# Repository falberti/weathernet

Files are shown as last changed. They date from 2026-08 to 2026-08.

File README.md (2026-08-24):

# WeatherNet

WeatherNet is a small telemetry platform for a network of DIY
environmental monitoring devices ("probes"). A probe reads sensor data
and device health metrics and reports them over mutual TLS to a server,
which validates the probe against a registry, stores the data in
TimescaleDB, and makes it visible in Grafana. Version 1 targets a
single Raspberry Pi probe and a single server, but the probe's sensor
framework and the server's registry are both built to add more probes
and hardware types later without a rewrite.

## Architecture

```
                          ┌──────────────────────────────────────────────────┐
                          │  Server VM (public IP, no DNS)                   │
                          │                                                  │
  ┌──────────┐  mTLS      │  ┌────────┐   verified    ┌────────┐             │
  │  Probe   │───────────▶│  │ nginx  │──cert CN hdr─▶│ django │             │
  │ (RPi,    │  HTTPS/443 │  │ (TLS + │               │        │──┐          │
  │ systemd, │            │  │ mTLS   │               └────────┘  │writes    │
  │ no       │            │  │ term.) │                           ▼          │
  │ Docker)  │            │  └────────┘               ┌────────────────────┐ │
  └──────────┘            │                           │ postgres +         │ │
                          │                           │ timescaledb ext.   │ │
                          │                           │ (registry tables + │ │
                          │                           │  sensor/health     │ │
                          │                           │  hypertables)      │ │
                          │                           └──────────┬─────────┘ │
                          │                                      │reads      │
                          │                                      ▼           │
                          │                                 ┌────────┐       │
                          │                                 │ grafana│       │
                          │                                 └────────┘       │
                          └──────────────────────────────────────────────────┘
```

Every telemetry payload goes `probe → nginx (mTLS termination) → Django
ingestion endpoint → TimescaleDB hypertables`. Probes never talk to
Postgres or Grafana directly, and Django cross-checks every probe's
identity (from its client certificate) against the registry before
writing anything -- deactivating a probe in Django Admin actually stops
its data, not just hides it. See [`PROJECT_SPEC.md`](PROJECT_SPEC.md)
for the full design rationale and [`docs/api-contract.md`](docs/api-contract.md)
for the exact ingestion payload schema.

Separately, each probe also maintains an outbound **WireGuard** tunnel
to the server, purely for operator troubleshooting (e.g. SSHing into a
probe sitting behind a home NAT). It's an independent channel from the
mTLS telemetry path above -- unrelated to probe authentication for
ingestion, and not gated by a probe's `is_active` flag. See
[Section 3](PROJECT_SPEC.md#3-architecture) and
[Section 5.8](PROJECT_SPEC.md#58-remote-access-via-wireguard-ongoing-operation)
of the spec.

A third path exists for exactly one moment per probe: **enrollment**. A
brand-new probe has no mTLS certificate yet, so it can't use mTLS to
bootstrap itself -- a single-use, short-lived token (generated in
Django Admin) stands in for that first credential exchange instead.
See [Section 5.7](PROJECT_SPEC.md#57-zero-touch-probe-enrollment) of
the spec for the full design.

## Prerequisites

**Server**: a VM with Docker and the Docker Compose plugin, a public
IP, and inbound access open on `443` (nginx/ingestion), Grafana's port
(`3000` by default), and the WireGuard UDP port (`51820` by default).

**Probe**: a Raspberry Pi (3 or newer) running a current Raspberry Pi
OS, Python 3, and network reachability to the server on `443`.

## Server setup

1. On the server, clone this repo and `cd server/`.
2. Generate the internal CA and server certificate (skip this if you'd
   rather let `scripts/setup.sh` do it for you -- it calls these
   automatically):
   ```bash
   ./pki/generate-ca.sh
   ./pki/generate-server-cert.sh <server-public-ip>
   ```
3. Run setup:
   ```bash
   ./scripts/setup.sh <server-public-ip>
   ```
   This generates `.env` (with a fresh `SECRET_KEY` and random
   passwords) if it doesn't already exist, builds and starts the Docker
   Compose stack, runs migrations (which also create the TimescaleDB
   hypertables and their compression/retention policies), prompts you
   to create a Django Admin superuser, and generates the server's
   WireGuard keypair and brings up its `wg0` interface.
4. When it finishes, the script prints the Grafana and Django Admin
   URLs and installs a systemd timer that keeps WireGuard peers in sync
   automatically -- no manual step needed there going forward.

## Probe setup

This is genuinely one command on the probe side -- zero-touch
enrollment (see above) means there's no manual certificate, UUID, or
WireGuard key exchange to do by hand.

1. In Django Admin, add an **Enrollment token**: fill in the probe's
   name and hardware type, save. The resulting page prints a one-time
   token and the *exact* command to run on the probe, including the
   server's IP and its certificate fingerprint (for TLS pinning) --
   nothing to copy from anywhere else.
2. On the probe device, clone this repo and `cd probe/`.
3. Run the command Django printed:
   ```bash
   ./scripts/setup.sh --server <server-public-ip> --token <token> --fingerprint <sha256-fingerprint>
   ```
   This creates a virtualenv, generates the probe's mTLS and WireGuard
   keypairs locally (private keys never leave the device), verifies the
   server's certificate against the given fingerprint before sending
   anything, exchanges the token for a signed certificate and an
   assigned WireGuard tunnel IP, writes `probe.yaml` and `wg0.conf`, and
   installs + starts both the `weathernet-probe` and `wg-quick@wg0`
   systemd services.
4. That's it. The probe should appear in Grafana within its report
   interval, and become SSH-reachable at its WireGuard tunnel IP from
   the server within about a minute (the timer installed during server
   setup picks it up automatically).

`--fingerprint` is optional but recommended -- without it, the probe
still enrolls, but has no way to confirm it's actually talking to your
server for that one bootstrap request (it prints a clear warning when
you skip it, rather than silently reducing the guarantee).

Once enrolled, open that `Probe` in Django Admin and optionally fill in
its location (a free-text description plus GPS coordinates) and owner
contact info (email, and an optional phone number) -- useful once you
have more than one or two probes and need to remember where a given one
physically is or who to ask about it. None of this affects enrollment or
ingestion; it's operator reference data only.

## Adding a second probe

Repeat the "Probe setup" steps above -- generate another token, run
`setup.sh` again with it. That's the entire multi-probe story for v1;
nothing on the server side needs to change, and there's no per-probe
bookkeeping (UUIDs, tunnel IPs, cert files) left to track by hand.

## Deploying updates

**Server**: `./server/scripts/deploy.sh` -- pulls, rebuilds images, runs
any new migrations, recreates changed containers, prints the deployed
commit.

**Probe**: `./probe/scripts/deploy.sh` -- pulls, reinstalls dependencies
into the existing virtualenv, restarts the systemd service, tails
recent logs.

Both refuse to run if the working tree has uncommitted changes.

## Adding a real sensor driver

v1 ships mostly mock sensors (see "Known limitations" below). To add a
real one:

1. Add a module under `probe/weathernet_probe/sensors/` implementing
   the `Sensor` interface from `sensors/base.py` (a `sensor_type` and a
   `read()` method).
2. Add one entry mapping a config name to your new class in
   `sensors/registry.py`.
3. Add that name to the `sensors:` list in a probe's `probe.yaml`.

Nothing in `main.py` or `transport.py` needs to change.

### BME680 wiring (I2C)

The included `bme680_temperature`/`bme680_humidity`/`bme680_pressure`/
`bme680_gas` drivers (`weathernet_probe/sensors/bme680.py`) expect the
sensor wired for I2C. Most inexpensive BME680 breakout boards expose 6
pins:

| Sensor pin | Pi pin (40-pin header) | Notes |
|---|---|---|
| VCC  | Pin 1 (3.3V) | **Not** 5V (pins 2/4) -- the BME680 is a 3.3V part |
| GND  | Pin 6 or 9 | |
| SCL  | Pin 5 (GPIO3, SCL1) | |
| SDA  | Pin 3 (GPIO2, SDA1) | |
| SDO  | GND | Sets the I2C address to `0x76`, which the driver assumes |
| CS | VCC (3.3V) | Forces I2C mode -- grounded or floating selects SPI instead |

Then enable I2C and confirm the sensor answers:

```bash
sudo raspi-config nonint do_i2c 0
sudo apt-get install -y i2c-tools
i2cdetect -y 1   # expect to see a device at address 76
```

**Edit `/etc/weathernet-probe/probe.yaml`'s `sensors:` list** (replace
or add to the mock entries) -- this is what actually turns the driver
on, wiring the sensor alone isn't enough:

```yaml
sensors:
  - bme680_temperature
  - bme680_humidity
  - bme680_pressure
  - bme680_gas
```

Then install the new dependencies and restart the daemon so it picks up
both the config change and the code:

```bash
cd ~/weathernet/probe
source venv/bin/activate && pip install -r requirements.txt && deactivate
sudo systemctl restart weathernet-probe
```

`bme680`/`smbus2` (the driver's dependencies) are Linux/I2C-specific and
only actually get exercised once a `bme680_*` sensor is configured --
importing the driver module without them installed, or without the
sensor wired up, is harmless (see the module's docstring), but reading
one without the package installed raises a clear, per-sensor
`SensorReadError` rather than crashing the daemon.

### BMP280, HTU21D-F wiring (I2C)

The included `bmp280_*` (`weathernet_probe/sensors/bmp280.py`) and
`htu21d_*` (`weathernet_probe/sensors/htu21d.py`) drivers both expect
I2C, and both chips can share the same two-wire bus (Pi pins 3/SDA and
5/SCL) since each answers to a different address. SPS30 is **not** on
this bus -- see its own UART section below, and why.

| Chip | I2C address | VCC pin | Notes |
|---|---|---|---|
| BMP280 | `0x77` | Pin 1 (3.3V) | See below -- this board's pin names and default address differ from a typical generic breakout. |
| HTU21D-F | `0x40` | Pin 1 (3.3V) | Fixed address, no SDO/address pin on this chip. **Not** 5V. |

Common to both: `GND` to Pin 6/9, `SCL` to Pin 5 (GPIO3/SCL1), `SDA`
to Pin 3 (GPIO2/SDA1).

BMP280 specifics -- this project's board is
[Adafruit #2651](https://www.adafruit.com/product/2651), which supports
both I2C and SPI off the same header, so its silkscreen doesn't say
`SDA`/`SCL` at all:

| Board pin | Function | Pi pin |
|---|---|---|
| `Vin` | Power (board has its own regulator, 3-5V in) | Pin 1 (3.3V) |
| `GND` | Ground | Pin 6 or 9 |
| `SCK` | I2C clock (doubles as SPI clock) | Pin 5 (GPIO3, SCL1) |
| `SDI` | I2C data (doubles as SPI MOSI) -- **this is your SDA** | Pin 3 (GPIO2, SDA1) |
| `SDO` | SPI-only (MISO) | Leave disconnected |
| `CS` | SPI-only (chip select) | Leave disconnected |

Leaving `SDO` disconnected matters beyond just "it's unused": this
board pulls `SDO` up to 3.3V through an onboard 10k resistor, so the
I2C address defaults to `0x77`, not the `0x76` a lot of cheaper generic
BMP280/BME280 breakouts default to (those instead pull `SDO`/`SDO`-
equivalent low unless you tie it to VCC). The driver
(`weathernet_probe/sensors/bmp280.py`) is set up for `0x77` accordingly
-- if you ever swap in a different breakout that defaults to `0x76`
instead, that's the one line to change. `3Vo` (the board's own
regulated 3.3V output) isn't used here -- it's meant for powering
*other* 3.3V-logic devices from this board, not an input.

Then enable I2C and confirm both chips answer, same as BME680:

```bash
sudo raspi-config nonint do_i2c 0
sudo apt-get install -y i2c-tools
i2cdetect -y 1   # expect to see devices at 40 and 77 -- SPS30 is not on this bus, see below
```

**Edit `/etc/weathernet-probe/probe.yaml`'s `sensors:` list** (replace or
add to the mock entries) with whichever of these you actually wired --
you don't have to enable all four:

```yaml
sensors:
  - bmp280_temperature
  - bmp280_pressure
  - htu21d_temperature
  - htu21d_humidity
```

Then install the new dependencies and restart the daemon so it picks up
both the config change and the code:

```bash
cd ~/weathernet/probe
source venv/bin/activate && pip install -r requirements.txt && deactivate
sudo systemctl restart weathernet-probe
```

A few things worth knowing about how these two differ from BME680:

- **BMP280 and HTU21D-F both report temperature.** Their `sensor_type`
  values are prefixed with the chip name (`bmp280_temperature_c`,
  `htu21d_temperature_c`) specifically so both can be wired and active
  at once -- e.g. to sanity-check one against the other during
  bring-up -- without colliding in storage or on a Grafana panel the
  way two `temperature_c` series would. BME680's own sensors keep their
  original generic names (`temperature_c`, etc.) for backward
  compatibility with already-stored data and the existing dashboard
  panels; this is a deliberate inconsistency, not an oversight.
- **BMP280 rejects readings outside the chip's own operating range**
  (-40..85°C, 300..1100 hPa -- Bosch's datasheet, not a guess) instead
  of reporting them. Hit for real: a corrupted I2C read once
  compensated into a plausible-looking 180°C that silently sat in
  Grafana for hours before anyone noticed, precisely because 180
  doesn't *look* like garbage the way an obviously-broken value would.
  Now that shows up as a `SensorReadError` in the log
  (`BMP280 reading 180.0C is outside the chip's own operating range`)
  and gets skipped for that cycle instead of polluting the stored
  data -- this doesn't fix whatever *caused* the bad read (I2C noise,
  a transient glitch, ...), it just stops it from reaching the
  dashboard unnoticed. If you see this warning recur, that's the
  signal something upstream needs investigating, not the driver being
  overly strict.

### SPS30 wiring (UART)

Unlike BMP280/HTU21D-F, this one is **not** on the I2C bus, deliberately
-- see "why UART, not I2C" below. It ships with a 5-pin JST ZHR
connector, not breakout header pins, and its pin assignment is `1=VDD,
2=RX, 3=TX, 4=SEL, 5=GND` (per Sensirion's datasheet Table 4 -- easy to
get wrong since several third-party wiring guides transcribe this table
incorrectly, and note that pins 2/3 are labeled `RX`/`TX` here, not
`SDA`/`SCL` -- I2C and UART share the same two physical pins but use
them differently). Pin 1 is the pin closest to the sensor's body, pin 5
is closest to the free end of the connector (Figure 1 in Sensirion's
datasheet).

**Wire colors are not standardized across cables/vendors** -- don't
trust a generic color guide found online; verify against the datasheet
figure for your own cable. For the pigtail that shipped with this
project's sensor, counted from the sensor body outward, the colors are
black-red-white-yellow-orange (same physical wires as when this was
wired for I2C -- only the pin *function* and the Pi-side pins they
connect to have changed):

| Pin | Wire color (this project's cable) | Pi pin | Notes |
|---|---|---|---|
| 1 (VDD) | black | Pin 2 or 4 (**5V**) | The sensor needs 5V to run its fan -- **not** 3.3V. Wire this and GND below directly, point-to-point -- not through the breadboard (see "why UART, not I2C"). |
| 2 (RX) | red | Pin 8 (GPIO14, **TXD**) | Sensor's RX to Pi's TX -- crossed over, as UART always is. |
| 3 (TX) | white | Pin 10 (GPIO15, **RXD**) | Sensor's TX to Pi's RX. |
| 4 (SEL) | yellow | **Leave disconnected** | Floating selects UART. This is the opposite of the I2C wiring (where SEL went to GND) -- if you're converting an existing I2C setup, disconnecting this wire is a required step, not optional. |
| 5 (GND) | orange | Pin 6 or 9 | Also direct/point-to-point, not through the breadboard. |

If you ever swap in a different SPS30 cable, re-derive this table from
the connector's physical pin 1/pin 5 position (per Sensirion's Figure
1) rather than assuming these same colors -- they're specific to this
cable, not a general SPS30 convention.

**Why UART, not I2C:** Sensirion's own datasheet recommends UART over
I2C for cable runs over ~20cm, citing "intrinsic robustness against
electromagnetic interference" -- and this is exactly what real hardware
bring-up confirmed necessary: on I2C, this sensor's fan motor reliably
knocked it off the shared bus every time `start_measurement()` spun it
up, even after ruling out every power-supply explanation in turn (a
proper DIN-rail PSU, and direct point-to-point VDD *and* GND wiring
bypassing the breadboard entirely). UART uses the Pi's dedicated serial
pins instead of the bus SDA/SCL shares with BMP280/HTU21D-F, so it
isn't exposed to whatever was coupling noise onto those lines.

**Raspberry Pi UART setup** -- on a Pi 3 (and 3B+/3A+/4B/Zero W), the
good hardware UART (PL011) is routed to the onboard Bluetooth radio by
default; the GPIO14/15 pins only get the "mini UART", whose baud rate
is tied to the variable CPU core clock and isn't reliable enough for
this. Free up the PL011 for the GPIO pins instead:

```bash
echo "dtoverlay=disable-bt" | sudo tee -a /boot/firmware/config.txt   # /boot/config.txt on older OS releases
sudo systemctl disable hciuart bluetooth
sudo raspi-config nonint do_serial_hw 0   # enable the UART hardware
sudo raspi-config nonint do_serial_cons 1 # disable login shell over serial -- required, see below
sudo reboot
```

The second `raspi-config` call matters as much as the first: by
default Raspberry Pi OS runs a login console on the serial port, which
will fight with the probe daemon for the same `/dev/ttyAMA0` -- both
disabling the console *and* enabling the UART hardware are required,
not just one or the other. After rebooting, confirm the device exists:

```bash
ls -l /dev/ttyAMA0
```

**Edit `/etc/weathernet-probe/probe.yaml`'s `sensors:` list**, same as
for the others -- this is what actually turns the driver on, wiring it
up alone isn't enough:

```yaml
sensors:
  - sps30_pm1_0
  - sps30_pm2_5
  - sps30_pm4_0
  - sps30_pm10
```

Then, same pattern as the others:

```bash
cd ~/weathernet/probe
source venv/bin/activate && pip install -r requirements.txt && deactivate
sudo systemctl restart weathernet-probe
```

A few things worth knowing about the SPS30 driver specifically:

- **Needs ~10 seconds after startup before its first real reading** --
  the fan has to physically spin up and the airflow has to stabilize
  before a mass-concentration reading means anything. The driver
  returns a clear `SensorReadError` ("still warming up") during that
  window rather than a garbage value; this is expected on every daemon
  (re)start, not a fault.
- **Its four `sps30_pm*` sensors share one physical device and one
  cached reading per cycle** (like BME680's four sensors do), since the
  chip only produces a new sample about once a second regardless of how
  many of the four are configured.
- **Self-recovers from a silent reset.** This driver only calls
  `start_measurement()` once, at process start -- if the chip's
  internal state ever gets reset without the process noticing (e.g. a
  brief brownout, or any other transient that bounces it back to
  Idle-Mode without killing the serial connection itself), it would
  otherwise report "not ready" forever, since Idle-Mode never produces
  new samples on its own. If no fresh data has arrived for over 30s,
  the driver re-issues `start_measurement()` automatically and logs
  `SPS30 had no fresh data for over 30s -- it may have silently reset
  to Idle-Mode; re-issued start_measurement()`. Seeing this
  occasionally (e.g. around a power event) is the recovery working as
  intended, not a fault to chase; seeing it constantly points back to
  the wiring/power checks above.
- **No ready-flag command over UART, unlike I2C.** The driver instead
  calls `read_measurement_values_uint16()` directly and treats the
  `struct.error` that Sensirion's own SHDLC library raises on an empty
  response frame (its way of saying "nothing new yet") as the
  not-ready signal -- confirmed against the actual library source, not
  assumed. If you ever see an *unrelated*-looking `struct.error`
  surface elsewhere, this is the first place to check.
- **Recovers from Sleep-Mode automatically.** If every command times
  out with `ShdlcSerialPort timed out while waiting for response` and
  `could not initialize SPS30 over UART` -- with no wiring change, and
  the fan's faint hum has gone silent -- the chip is almost certainly
  in Sleep-Mode, which disables the UART interface entirely
  (datasheet §4.1 "Sleep"). This driver never sends the Sleep command
  itself, but the chip can end up there regardless of what put it
  there. Per the datasheet's own documented recovery (§5.3.5
  "Wake-up"): sending the Wake-up command twice in a row wakes it back
  up in software, no power cycle needed -- the first call gets no
  response (the interface is still off when it's sent) but activates
  it; the second succeeds normally. The driver does this automatically
  on every fresh initialization, so this should self-heal on the next
  reporting cycle without you doing anything.

## Reaching a probe remotely

SSH into the server first (your existing access to it, unrelated to
WireGuard), then hop to the probe's tunnel IP:

```bash
ssh <server-user>@<server-public-ip>
ssh <probe-user>@10.10.0.x
```

If the server's `.env` has `SERVER_SSH_PUBLIC_KEY_HOST_PATH` pointing at
a real key (the default is `/home/ubuntu/.ssh/id_ed25519.pub`), the
second hop needs **no key setup at all** -- enrollment installs that
public key into the probe's `authorized_keys` automatically. If it
wasn't configured, or the probe was enrolled before that server setting
existed, the fallback is SSH agent forwarding from your own laptop
(so the private key never has to live on the server):

```bash
ssh-add -l                          # confirm your key is loaded locally
ssh -A <server-user>@<server-public-ip>
ssh <probe-user>@10.10.0.x          # uses the forwarded agent
```

The server is the only bastion into the WireGuard subnet for v1 -- your
own laptop isn't a peer. This works even for a probe you've deactivated
in Django Admin (`is_active` only gates telemetry ingestion, not
WireGuard reachability) and even if its mTLS certificate has been
revoked. A systemd timer installed during server setup re-runs
`wireguard/sync-peers.sh` every minute, so a newly enrolled probe (or
one whose WireGuard fields you edited by hand in Django Admin) becomes
reachable on its own -- run that script manually only if you don't want
to wait for the next tick.

## Known limitations of v1

- **Mostly mock sensors.** Real drivers exist for BME680 (temperature,
  humidity, pressure, gas resistance), BMP280 (temperature, pressure),
  HTU21D-F (temperature, humidity), and SPS30 (PM1.0/2.5/4.0/10
  particulate mass concentration) -- see "Adding a real sensor driver"
  above and `weathernet_probe/sensors/`. A wind vane/anemometer and a
  rain gauge are still not implemented.
- **Raspberry Pi only.** No Arduino / non-Linux probe support yet.
- **No certificate rotation or revocation.** Enrollment solves
  *issuance*, not the full lifecycle -- issued certs are long-lived,
  there's no renewal flow, and no CRL/OCSP. Deleting a `Probe` row stops
  ingestion (Django 404s it) but doesn't cryptographically invalidate
  the certificate -- nginx would still complete a TLS handshake with it.
- **No rate limiting on `/api/v1/enroll`.** The token itself (32 bytes
  of entropy) is the only defense against guessing; there's no request
  throttling on top of it.
- **The CA private key is readable by the `django` container.**
  Zero-touch enrollment needs it to sign CSRs synchronously -- a
  deliberate trade-off (see `PROJECT_SPEC.md` Section 5.7), not an
  oversight. A more isolated design would move signing into a separate,
  minimal process.
- **No WireGuard access for the operator's own device.** The server is
  the only bastion into the WireGuard subnet; reaching a probe means
  SSHing into the server first, then hopping to the probe's tunnel IP.
- **No alerting.** Grafana alert rules can be added manually; none are
  provisioned.
- **No browser-trusted HTTPS for Django Admin / Grafana.** There's no
  DNS name yet, so their TLS is either self-signed or plain HTTP.
  Treat the server as trusted-network-only for admin access.
- **Single server, single database.** No HA, clustering, or failover.

## Troubleshooting

- **Probe logs**: `journalctl -u weathernet-probe -f` on the probe.
  Check `/var/lib/weathernet-probe/spool.jsonl` -- if it's growing, the
  probe can't reach the server (spooled readings are retried every
  cycle).
- **nginx / mTLS handshake failures**: `docker compose logs nginx` on
  the server, for a request to `/api/v1/ingest`. A `401` means no
  client certificate was presented at all; `403` means one was
  presented but failed verification against the internal CA.
- **Rejected ingests**: `docker compose logs django` on the server. A
  `404` means the probe's UUID isn't registered; `403` here means it's
  either inactive or the certificate CN doesn't match the payload's
  `probe_id` (same status code as the nginx-layer rejection above, but
  a different log to check).
- **Failed enrollment**: `docker compose logs django` on the server, for
  a request to `/api/v1/enroll`. `404` means the token doesn't match
  any `EnrollmentToken` (typo, or copied from the wrong Admin page);
  `410` means it's expired or was already used -- generate a new one.
  `400` usually means a CSR problem; `409` means `WIREGUARD_SUBNET` is
  exhausted. On the probe side, `enroll.py` prints the server's error
  detail directly, so the probe's own terminal output is often the
  fastest place to look first.
- **WireGuard tunnel not connecting**: run `sudo wg show wg0` on both
  the server and the probe. If the keys match on both sides but the
  server's peer entry shows no `endpoint`/`latest handshake` while the
  probe shows bytes sent but none received, the server is never
  actually seeing the probe's packets -- almost always the WireGuard UDP
  port not actually open. Confirm with
  `sudo tcpdump -i any udp port 51820 -n` on the server while the probe
  is running (it retries every 25s): no packets at all means the block
  is upstream (the cloud provider's security group); packets arriving
  but no handshake means something local is dropping them after
  arrival. **Check the actual firewall in use, not just `ufw`** -- some
  providers manage a local `iptables`/`nftables` ruleset automatically
  from their console's security group (`sudo iptables -L INPUT -n -v`
  or `sudo nft list ruleset`), and a rule added directly on the host may
  not survive a reboot or the next security-group sync -- the durable
  fix is opening the port in the provider's own console, not just
  locally. On the server, a missing peer entry entirely (not just a
  stuck handshake) means `wireguard/sync-peers.sh` hasn't been run since
  that probe's keys/IP were saved in Django Admin.

See [`server/README.md`](server/README.md) and
[`probe/README.md`](probe/README.md) for component-specific detail.

## License

This repository is [MIT-licensed](LICENSE), including everything under
[`3d-printing/`](3d-printing/) so far. That said, 3D-printable designs there
could in principle start from or modify someone else's
differently-licensed model in the future -- check each part's own
`LICENSE`/`README.md` before reusing it if one exists (see
[`3d-printing/README.md`](3d-printing/README.md) for the convention).

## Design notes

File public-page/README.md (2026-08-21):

# WeatherNet public page

A self-contained PHP page for external, PHP-only hosting (e.g.
falberti.it) that shows current readings and a map publicly. It does
**not** run on the WeatherNet VM.

## Architecture

Two scripts with very different jobs:

- **`sync.php`** -- run every 10 minutes by your hosting's cron. The
  only thing here that ever talks to the VM: fetches
  `/api/v1/public/summary` and `/api/v1/public/history` (see
  [`probes/views.py`](../server/django_app/probes/views.py)
  `PublicSummaryView` / `PublicHistoryView` and
  [`docs/api-contract.md`](../docs/api-contract.md)) and upserts the
  result into a local MySQL table, `probe_cache` (`schema.sql`).
- **`index.php`** -- what visitors see. Reads only from that MySQL
  table, never from the VM. A burst of visitors here never becomes a
  burst of requests against the VM -- the cron interval is the only
  thing that talks to it, at a fixed, predictable rate.

This also solves the certificate problem cleanly: the VM's own TLS
certificate is signed by this project's private CA (needed for probe
mTLS), so it's not publicly trusted -- a browser landing on the VM
directly would show a warning. Only `sync.php` (server-side, PHP to
Django, verified against the private CA explicitly -- see below) ever
makes that connection; visitors only ever see this page's own
(regularly issued) certificate.

`probe_cache` holds one row per probe, overwritten on every `sync.php`
run -- it's a cache of the latest fetch, not an accumulating history.
`sync.php` still fetches and stores a 24h history window per probe
(`history_json`) even though `index.php` doesn't currently render it
(a chart view was tried and removed) -- the data's already there if
that comes back later.

## What's published, and what isn't

Per probe: name, hardware type, latest temperature/humidity/pressure/
gas-resistance readings, the air quality index (the real EPA standard
when the probe has SPS30 PM data, otherwise the older BME680-only
heuristic -- `index.php`'s `aqi_label()` renders the two differently,
see its docblock), and
**coordinates rounded to `PUBLIC_LOCATION_PRECISION_DECIMALS`** (2 by
default, ~1km precision, set server-side) -- enough to place a probe
in its general area (and plot it on the map) without revealing which
building it's in.

Never published: exact address, owner email, owner phone. Those never
leave the VM's `/api/v1/public/*` responses in the first place (see
the Django views), so there's nothing to accidentally leak here even
if this page's template changes later.

## Telegram daily digest

A link in the footer (only shown if `TELEGRAM_BOT_USERNAME` is set)
opens `t.me/<username>` -- pressing Start there is the entire sign-up
flow. Everything after that happens inside Telegram, not on this page:
the bot asks for a place name, geocodes it (Nominatim, open, no API
key), and subscribes that chat to a daily summary if a probe is close
enough. See the VM-side `server/django_app/subscriptions/` app
(`bot.py` for the conversation, `management/commands/send_daily_digest.py`
for the once-a-day send) -- none of that logic lives here, this page
only carries the link.

## Layout

- `index.php` -- the page. Reads `probe_cache` via `db.php`, renders
  the current-reading cards and an OpenStreetMap/Leaflet map (marker
  per probe, colorable by temperature/humidity/pressure/air quality).
- `i18n.php` -- Italian/English/French/German strings plus
  `detect_locale()`. Priority: an explicit choice from the flag
  dropdown (`?lang=xx`, top-right on `index.php`) beats a remembered
  previous choice (`weathernet_lang` cookie, set only when a request
  carries a fresh `?lang=`) beats the browser's `Accept-Language`
  header beats English as the last-resort default. The cookie is
  first-party, stores only the language the visitor just explicitly
  picked, and is never set on a plain page load -- see the comment at
  the top of `i18n.php` for why that's exempt from cookie consent
  under ePrivacy/GDPR the same way the rest of this otherwise
  cookie-free site is.
- `sync.php` -- the cron entrypoint. Fetches both VM endpoints and
  upserts `probe_cache`. Refuses to run outside a CLI context (i.e. a
  browser hitting its URL directly gets a 403) -- `.htaccess` also
  blocks it as a second layer.
- `db.php` -- a few lines wrapping `PDO` construction, shared by both
  scripts above.
- `config.php` (you create this, gitignored) -- `VM_HOST`/`API_KEY`
  (`sync.php` only), `DB_HOST`/`DB_NAME`/`DB_USER`/`DB_PASS` (both
  scripts), and `TELEGRAM_BOT_USERNAME` (`index.php` only). A `.php`
  file that `return`s an array, not a plain-text `.env` -- see the
  comment at the top of `config.php.example` for why that's the safer
  choice on generic PHP hosting: any PHP host executes `.php` files
  rather than serving their source, so this needs no `.htaccess` (or
  equivalent) rule to stay confidential, unlike a text file whose
  protection depends on the web server being Apache with
  `AllowOverride` enabled for this directory and the rule file having
  actually been uploaded correctly.
- `schema.sql` -- the one table this needs. Run it once.
- `.htaccess` -- blocks direct URL access to `config.php` (defense in
  depth, not the load-bearing protection -- see above), `*.pem`, and
  `sync.php`.

## Deploy

1. On the VM, generate an API key and put it in `server/.env`:
   ```bash
   python3 -c "import secrets; print(secrets.token_urlsafe(32))"
   ```
   Set `PUBLIC_SUMMARY_API_KEY=<that value>` in `server/.env`, then
   `docker compose restart django`. (A fresh install's `setup.sh`
   generates this automatically -- this manual step is only needed
   because the endpoint was added after your server was already set up.)

2. Copy the VM's CA certificate (public, not secret) to your machine:
   ```bash
   scp <vm-user>@<vm-ip>:~/weathernet/server/pki/ca/ca.cert.pem ./weathernet-ca.pem
   ```

3. In your hosting control panel, create a MySQL database and user,
   then run `schema.sql` against it (phpMyAdmin's "Import" tab, or the
   `mysql` CLI if you have shell access).

4. Copy `config.php.example` to `config.php` and fill in `VM_HOST`,
   `API_KEY` (from step 1), and the MySQL credentials from step 3. If
   the Telegram bot (see above) is set up, also set
   `TELEGRAM_BOT_USERNAME` to show the link -- leave it blank to hide it.

5. Upload `index.php`, `i18n.php`, `sync.php`, `db.php`, `config.php`,
   `weathernet-ca.pem`, and `.htaccess` (all in the same directory) to
   your PHP hosting.

6. Add a cron job for `sync.php`, type **PHP** (not HTTP/HTTPS -- this
   runs it via the CLI, which is also what makes `sync.php`'s own
   "refuse to run outside CLI" guard let it through). Command: just
   `sync.php` (the UI already prefixes `./`). Frequency: manual
   configuration, `*/10` in **Minuto**, `*` everywhere else -- your
   panel's manual mode has a 10-minute floor, matching the "every 5 or
   10 minutes" ask.

7. Trigger it once by hand if your panel allows a manual "run now", or
   just wait up to 10 minutes, then open the page. If it still shows
   "Dati momentaneamente non disponibili": check your host's cron
   execution log or PHP error log for what `sync.php` printed (it logs
   the HTTP status and curl error on a failed VM fetch, and the MySQL
   error on a failed connection); or query the VM directly to rule
   that leg out:
   ```bash
   curl -s -H "X-Api-Key: <key>" https://<vm-ip>/api/v1/public/summary \
     --cacert server/pki/ca/ca.cert.pem
   ```
   If that returns data but the page still doesn't, the problem is
   between `sync.php` and MySQL -- double-check the `DB_*` values in
   `config.php` and that `schema.sql` was actually run.

## The map

Leaflet.js + OpenStreetMap tiles, loaded from their public CDN (no API
key needed, unlike Google Maps). One marker per probe today; the radio
controls above the map recolor markers by whichever parameter is
selected, using the same data already on the page -- no extra request.
With a single probe this is a colored point, not a heatmap; the
multi-probe case (Section 12 of `PROJECT_SPEC.md`) reads from this
exact same per-probe coordinate/reading data, so a real interpolated
heatmap (e.g. the `leaflet.heat` plugin) can be added later without
changing what's fetched, just how it's drawn.

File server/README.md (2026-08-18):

# WeatherNet Server

Docker Compose stack: `postgres` (TimescaleDB extension), `django`
(ingestion + enrollment API + Admin, via gunicorn), `nginx` (mTLS
termination, published on `443`), `grafana` (published on `3000`),
`telegram-bot` (long-polls Telegram for the daily-digest subscription
bot, see below). Only `nginx` and `grafana` are reachable from outside
the compose network -- see the comments in `docker-compose.yml`.

See the top-level [`README.md`](../README.md) for the setup walkthrough
and [`PROJECT_SPEC.md`](../PROJECT_SPEC.md) for the full design.

## Layout

- `pki/` -- `generate-ca.sh` and `generate-server-cert.sh`, run once at
  server setup. Generated key material lands under `pki/ca/` and
  `pki/server/`, gitignored. There's no per-probe certificate script
  anymore -- issuance happens synchronously inside the `/api/v1/enroll`
  view (`django_app/probes/ca.py`), which is why `pki/ca/ca.key.pem` is
  also bind-mounted (read-only) into the `django` container.
- `wireguard/` -- the operator-troubleshooting WireGuard tunnel, a
  channel entirely separate from mTLS/telemetry (see
  [`PROJECT_SPEC.md`](../PROJECT_SPEC.md) Section 5.8).
  `generate-server-keys.sh` creates the server's keypair (gitignored,
  private key never leaves the host); `sync-peers.sh` regenerates
  `/etc/wireguard/wg0.conf` from every `Probe` with WireGuard fields set
  (via the `generate_wireguard_peers` management command) and applies
  it live. `sync-peers.service`/`sync-peers.timer` run it automatically
  every minute (installed by `scripts/setup.sh`). All of this runs on
  the VM host directly, not inside Docker.
- `django_app/` -- the Django project.
  - `probes/` -- the registry, plus enrollment: `models.py` (`Probe`,
    with optional location/coordinates and owner contact fields for
    operator reference, plus `EnrollmentToken`), `admin.py` (generates a
    token and prints the exact probe-side command when you add one),
    `views.py` (`POST /api/v1/enroll`), `ca.py` (CSR signing via
    `cryptography`), `wireguard.py` (tunnel IP allocation + peer
    rendering), `ssh.py` (best-effort read of the VM's own SSH public
    key, handed to a probe during enrollment -- see
    `SERVER_SSH_PUBLIC_KEY_HOST_PATH` in `.env.example`).
  - `telemetry/` -- the ingestion endpoint and the two TimescaleDB
    hypertable models (`SensorReading`, `ProbeHealth`).
  - `subscriptions/` -- the Telegram daily-digest bot (see "Telegram
    daily digest" below): `models.py` (`WeatherSubscription`),
    `bot.py` (conversation/command handling), `geocoding.py`
    (Nominatim), `matching.py` (nearest-active-probe lookup),
    `management/commands/telegram_bot_poll.py` (the long-running
    poll loop -- `telegram-bot` service's command) and
    `send_daily_digest.py` (the once-a-day send).
- `nginx/nginx.conf.template` -- rendered into `nginx.conf` (gitignored)
  by `scripts/setup.sh` -- re-run it (safe/idempotent) after pulling a
  change to this file, `deploy.sh` alone does not re-render it.
  `/api/v1/ingest` is the only mTLS-gated location; `/api/v1/enroll`,
  `/api/v1/public/` (rate-limited instead, see `probes/views.py`
  `PublicSummaryView`/`PublicHistoryView`), and `/admin/` share the
  rest of the port without requiring a client certificate.
- `grafana/provisioning/` -- datasource and one example dashboard,
  loaded automatically on Grafana's first boot.
- `scripts/setup.sh` / `scripts/deploy.sh` -- see the top-level README.
- `scripts/send-daily-digest.sh` + `scripts/weathernet-daily-digest.service`/`.timer`
  -- installed by `setup.sh` once `TELEGRAM_BOT_TOKEN` is set (same
  pattern as `wireguard/sync-peers.*` -- a host systemd timer running a
  management command inside the already-running `django` container via
  `docker compose exec`).

## Running Django management commands directly

```bash
docker compose exec django python manage.py <command>
```

## Running the Django test suite

```bash
docker compose exec django python manage.py test
```

Covers the ingestion view (valid payloads accepted, unknown/inactive
probes and CN/body mismatches rejected -- `telemetry/tests.py`) and the
enrollment view (`probes/tests.py`): a valid token enrolls a probe with
the certificate CN forced to the assigned UUID; unknown/expired/reused
tokens are rejected with the right status codes; a malformed CSR or an
exhausted WireGuard subnet leaves the token unconsumed; and a dedicated
`TransactionTestCase` fires several genuinely concurrent redemption
requests for the same token at real threads to prove the
`select_for_update()` locking in `views.EnrollView` actually prevents
double-redemption under a race, not just in the easy sequential case.
`subscriptions/tests.py` covers the haversine distance formula,
geocoding (Nominatim requests mocked), nearest-active-probe matching,
every bot command (Telegram API calls mocked), and the daily digest
command (nearest-probe skip logic, yesterday's aggregate correctness,
the one-time "probe now in range" notice).

## Telegram daily digest

Anyone can subscribe to a daily weather summary for a place of their
choice by messaging the bot on Telegram -- the whole flow (giving a
place name, checking whether a probe is close enough, `/list`/`/remove`/
`/stop`) happens inside Telegram, there's no web form for it (see
`PROJECT_SPEC.md` Section 3 and `public-page/README.md`).

Setup, one time:

1. In Telegram, message **@BotFather** and send `/newbot`. Follow its
   prompts (it asks for a display name and a `@username` ending in
   `bot`). It replies with a token that looks like
   `123456789:AAF...`.
2. Put that token in `server/.env` as `TELEGRAM_BOT_TOKEN`, and the
   `@username` it gave you (without the `@`) as
   `TELEGRAM_BOT_USERNAME`.
3. `docker compose up -d telegram-bot` (or just re-run
   `scripts/deploy.sh`/`setup.sh`, which brings up every service).
4. Re-run `scripts/setup.sh <public-ip>` once more -- with
   `TELEGRAM_BOT_TOKEN` now set, this is what installs the daily-digest
   systemd timer (step 12); it's skipped with a message if the token
   is still blank.
5. On the public page (`public-page/`), set `TELEGRAM_BOT_USERNAME` in
   *its own* `.env` too, to show the subscribe banner there.

`SUBSCRIPTION_MAX_DISTANCE_KM` (default 15) controls how close a
subscription's location must be to an active probe to receive the
digest -- temperature/humidity/pressure stay reasonably representative
at that scale; air quality from a single BME680 is much more
hyperlocal, but there's no better distance-based proxy with
single-sensor probes. Change it in `.env` and restart `django` and
`telegram-bot`.

Send a digest manually (e.g. to test without waiting for the timer):

```bash
docker compose exec django python manage.py send_daily_digest
```

## TimescaleDB notes

The `telemetry` app's migrations (`0001`-`0005`) enable the extension,
create the tables, convert them to hypertables, and set up compression
(`TELEMETRY_COMPRESS_AFTER_DAYS`, default 7) and retention
(`TELEMETRY_RETENTION_DAYS`, default 90) policies from `.env`. See the
comments in `telemetry/migrations/0003_hypertables.py` for why the
default Django primary key had to be replaced with a composite one.

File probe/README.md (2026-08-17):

# WeatherNet Probe

A plain-Python (no containers) daemon that runs as a systemd service:
reads configured sensors and device health metrics on an interval, and
reports them to the server over mutual TLS.

See the top-level [`README.md`](../README.md) for the setup walkthrough
and [`PROJECT_SPEC.md`](../PROJECT_SPEC.md) for the full design.

## Layout

- `weathernet_probe/main.py` -- daemon entrypoint / main loop.
- `weathernet_probe/config.py` -- loads and validates `probe.yaml`.
- `weathernet_probe/health.py` -- real CPU/mem/disk/temperature metrics
  via `psutil` and the Pi's thermal zone file.
- `weathernet_probe/transport.py` -- the mTLS HTTPS client.
- `weathernet_probe/spool.py` -- on-disk retry queue for failed sends.
- `weathernet_probe/sensors/` -- the pluggable sensor framework:
  `base.py` (the `Sensor` interface), `registry.py` (config name →
  driver class), `mock.py` (no hardware needed), `bme680.py` (real
  temperature/humidity/pressure/gas over I2C -- see the top-level
  README for wiring; safe to import without the `bme680` package or
  real hardware present, only reading a sensor requires either).
- `config/probe.example.yaml` -- documents `probe.yaml`'s schema for
  reference/manual editing later. Not part of the normal setup path --
  `scripts/enroll.py` writes the real one automatically.
- `config/weathernet-probe.service` -- systemd unit template.
- `scripts/setup.sh` -- the one command an operator runs, per
  [`PROJECT_SPEC.md`](../PROJECT_SPEC.md) Section 5.7/8.2: installs
  dependencies (including `wireguard-tools`), calls `enroll.py`,
  installs and starts both systemd services.
- `scripts/enroll.py` -- does the actual enrollment: detects hardware
  type, generates the mTLS keypair + CSR and the WireGuard keypair
  locally via `openssl`/`wg` (private keys never leave this device),
  optionally pins the server's TLS certificate by SHA-256 fingerprint,
  calls `POST /api/v1/enroll`, and writes `probe.yaml` and
  `/etc/wireguard/wg0.conf` from the response. If the response includes
  the server's SSH public key, also appends it to `authorized_keys` for
  the user named by `--ssh-user` (resolved via `pwd.getpwnam()`, since
  this script itself runs under `sudo` and can't trust `$HOME`) -- see
  `PROJECT_SPEC.md` Section 5.7 step 7. No new code under
  `weathernet_probe/` -- this is a standalone script, not part of the
  daemon package, and doesn't add a `cryptography` dependency to the
  probe's runtime requirements (it shells out to `openssl`/`wg`
  instead, consistent with keeping this side of things light -- see
  Design constraints in the spec).

## Running the tests

```bash
python3 -m venv venv
source venv/bin/activate
pip install -r requirements-dev.txt
pytest
```

Covers the sensor registry (mock sensors return values in the expected
shape, unknown names are rejected) and the spool (append/pop ordering,
cap enforcement, corrupt-line handling).

## Adding a real sensor driver

1. Add a module under `weathernet_probe/sensors/` implementing the
   `Sensor` interface from `sensors/base.py`.
2. Add one entry to `SENSOR_REGISTRY` in `sensors/registry.py`.
3. Reference the new name in a probe's `sensors:` list in
   `probe.yaml`.

Nothing in `main.py` or `transport.py` needs to change -- that's the
whole point of the registry indirection.

## Operating a running probe

```bash
journalctl -u weathernet-probe -f            # tail logs
systemctl status weathernet-probe            # current state
wc -l /var/lib/weathernet-probe/spool.jsonl  # backlog size (if any)
sudo wg show wg0                             # WireGuard tunnel status
```

A growing spool file means the probe can't currently reach the server;
it retries the whole backlog, oldest first, every reporting cycle. The
WireGuard tunnel (`wg-quick@wg0.service`) is a separate, independent
systemd service from `weathernet-probe` -- used only for operator SSH
access via the server, unrelated to telemetry reporting (see
[`PROJECT_SPEC.md`](../PROJECT_SPEC.md) Section 5.8).

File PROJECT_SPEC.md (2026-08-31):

# WeatherNet — Telemetry Platform for Distributed Weather Probes

## 1. Overview

WeatherNet is a small telemetry platform for a network of environmental
monitoring devices ("probes"). Version 1 targets a single Raspberry Pi probe
reporting to a single server, but the codebase must be structured so that
additional probes and hardware types can be added later without rework.

**Components:**

- **Server**: a single Docker Compose stack (Django, PostgreSQL with the
  TimescaleDB extension, Grafana, and an Nginx reverse proxy) running on a
  VM with a public IP and no DNS record. Time-series data lives as
  hypertables in the same Postgres instance Django already uses for its own
  tables — there is deliberately no separate time-series database service.
- **Probe**: a lightweight, non-containerized Python application running as
  a systemd service on resource-constrained devices (starting with a
  Raspberry Pi). It reads sensor data through a pluggable driver interface
  and reports device health metrics.
- **Transport**: probes authenticate to the server exclusively via mutual
  TLS (mTLS). There is no username/password auth on the ingestion path.

This document is the implementation brief for the first version of the
codebase. Follow it section by section; where a decision was deliberately
left open for a future version, it is called out explicitly in
[Section 12](#12-explicitly-out-of-scope-for-v1).

## 2. Goals for v1

- A working, end-to-end path: probe reads mock sensor data + real device
  health metrics → sends them over mTLS → Django validates the probe against
  its registry → data lands in TimescaleDB hypertables → visible in Grafana.
- A minimal Django Admin-based UI to register/view probes (no custom
  frontend).
- One-shot setup scripts for both the server and a probe, and simple deploy
  scripts to pull and apply codebase updates on each side.
- A hardware abstraction layer on the probe side so that swapping in real
  sensor drivers, or supporting a Raspberry Pi 4/5 instead of a 3, is a
  matter of configuration and adding a driver module — not restructuring the
  app.
- All code, comments, docstrings, commit messages, and documentation in
  US English.

## 3. Architecture

```
┌────────────────────────────────────────────────────┐
│ Probe                                              │
│ (Raspberry Pi, systemd service, not containerized) │
└────────────────────────────────────────────────────┘
  │
  │  mTLS client cert over HTTPS/443
  ▼
┌────────────────────────────────────────────────────────┐
│ nginx                                                  │
│ (TLS termination, verifies client cert against the CA) │
└────────────────────────────────────────────────────────┘
  │
  │  verified cert CN forwarded as X-Client-Cert-CN
  ▼
┌───────────────────────────────────────────┐
│ django                                    │
│ (checks probe registry, writes telemetry) │
└───────────────────────────────────────────┘
  │
  │  writes
  ▼
┌─────────────────────────────────────────────┐
│ postgres + timescaledb extension            │
│ registry tables + sensor/health hypertables │
└─────────────────────────────────────────────┘
  │
  │  reads
  ▼
┌─────────┐
│ grafana │
└─────────┘

All boxes except "Probe" run inside the Server VM (public IP, no DNS).
```

**Data flow decision (do not deviate without discussion):** probes never
talk to Postgres or Grafana directly. Every telemetry payload goes
`probe → nginx (mTLS termination) → Django ingestion endpoint → TimescaleDB
hypertables`. Django is the single point where a probe's identity (from its
client certificate) is cross-checked against the probe registry (must exist
and be marked active) before anything is written. This keeps the registry
authoritative: deactivating a probe in Django Admin actually stops its data
from being accepted, not just from being displayed.

**Why TimescaleDB instead of a separate time-series database (e.g.
InfluxDB):** at this project's scale — a handful of probes reporting every
few minutes — the storage-efficiency gap between InfluxDB, TimescaleDB, and
purpose-built engines like TDengine is negligible in absolute terms; that
gap only shows up at a scale (millions of devices) this project will never
reach. What does matter for a v1 is running the fewest possible services.
Because TimescaleDB is a Postgres extension, the sensor/health hypertables
live in the exact same Postgres instance Django already needs for its own
tables — one database service to run, back up, and reason about instead of
two.

Django's own HTTP port must **not** be published outside the Docker
network — only nginx is reachable from outside the compose stack for the
ingestion path. Grafana may be published on its own port for the operator's
own dashboard access (see Section 5.4).

**A second, independent channel: WireGuard remote access.** Separate from
the telemetry path above, each probe also maintains an outbound WireGuard
tunnel to the server, so the operator can reach a probe for troubleshooting
even when it's behind a home NAT with no port forwarding:

```
  ┌──────────┐  WireGuard (UDP)      ┌────────────────────┐
  │  Probe   │───────────────────────▶│  Server: wg0        │
  │ wg0      │  probe-initiated,      │  (runs on the VM    │
  │ 10.10.0.x│  keeps itself open     │  host, not in       │
  └──────────┘  via keepalive         │  Docker — see 5.7)  │
                                       │  10.10.0.1          │
                                       └──────────┬───────────┘
                                                   │ operator SSHes into
                                                   │ the server first, then
                                                   ▼ hops to 10.10.0.x
                                          operator's own SSH session
```

This is deliberately a **separate** system from mTLS/telemetry: it exists
purely for human operator access when something's wrong, it's not part of
the data path, and it should not be conflated with probe authentication for
ingestion. A probe with a revoked mTLS cert can still (and should still) be
reachable over WireGuard so you can go fix it.

**A third path, used exactly once per probe: enrollment.** A brand-new
probe has no client certificate yet, so it obviously can't use mTLS to
bootstrap itself — that's a chicken-and-egg problem every enrollment
scheme has to solve somehow. WeatherNet solves it with a short-lived,
single-use token instead of a permanent credential; the full design is in
Section 5.7. The enrollment endpoint and Django Admin share nginx's port
443 with the ingestion endpoint but, unlike ingestion, don't require a
client certificate at all — nginx is configured with `ssl_verify_client
optional_no_ca` at the server level (accept the TLS connection either way,
without hard-rejecting even a *presented*-but-invalid cert, which plain
`optional` would still do), and it's the `/api/v1/ingest` location block
specifically — not Django, and not nginx's SSL layer globally — that
explicitly checks `$ssl_client_verify` and rejects there if it isn't
`SUCCESS`, before ever proxying to Django. See Section 5.1 for exactly why
`optional_no_ca` is the correct directive here and `optional`/`on` are not,
and Section 7 for how the two endpoints differ.

**A fourth path: a public, read-only API for an external page.**
Unlike the three paths above, this one is meant to be consumed from
*outside* the mTLS/admin trust boundary entirely — by the server-side
code of a page hosted on a completely different domain (e.g. a
PHP-only host), so that visitors never connect to the VM directly and
never see its self-signed certificate (Section 12 notes why the VM
itself has no browser-trusted cert in v1). `GET /api/v1/public/summary`
(current readings) and `GET /api/v1/public/history` (recent per-probe
time series, for charts) share nginx's port with `/api/v1/enroll` and
`/admin/` under a `/api/v1/public/` prefix location — no client
certificate required — but since neither has a per-request credential
of its own (a probe's enrollment token, an admin's session), both are
gated by the same static, shared API key (`PUBLIC_SUMMARY_API_KEY`,
checked in each view) and rate-limited at the nginx layer, since the
URL is otherwise reachable by anyone who finds it. `summary` returns
coordinates rounded to a coarser precision than what's stored
(`PUBLIC_LOCATION_PRECISION_DECIMALS`) and neither endpoint ever
includes `location_address` or owner contact fields — see Section 7.3/7.4.

The reference external page lives in `public-page/` at the repo root
(not part of the server or probe components — it does not run on the
VM at all, and is the only thing in this repo written in PHP rather
than Python). It does not call the VM directly: `public-page/sync.php`,
triggered by the *external host's* own cron (not this project's
`server`/`probe` components) every 10 minutes, is the only thing that
calls `/api/v1/public/summary` and `/api/v1/public/history` — it
upserts the result into a small MySQL table on that same external
host, then deletes any row for a probe no longer present in that
response (deactivated or removed `Probe`s don't just stop being
updated — they're actively pruned, so the cache can't outlive the API's
own `is_active` filter). `public-page/index.php`, what visitors
actually load, reads only from that MySQL table. This decouples visitor traffic from VM load
entirely: however many people load the page in a burst, the VM only
ever sees one request pair per cron interval, at a fixed and
predictable rate — the nginx rate limit above is a backstop, not the
thing actually controlling load in the common case. See
`public-page/README.md` for the full design and deploy steps.

`public-page/`'s own secrets (the API key above, MySQL credentials)
live in `config.php`, a `.php` file that `return`s an array — not a
plain-text `.env`. This matters specifically because `public-page/`
runs on arbitrary external PHP hosting this project doesn't control:
a `.env`'s confidentiality depends on the web server being Apache with
`AllowOverride` enabled for that directory and an `.htaccess` rule
having actually been uploaded correctly, none of which is guaranteed
on generic/budget hosting. A `.php` file needs none of that — any host
serving this page at all is, by definition, executing `.php` files
rather than serving their source, so a direct request to `config.php`
returns a blank page (the `return` ends the script before anything is
echoed), never the secrets. `.htaccess` still denies it directly
(`public-page/.htaccess`), but as defense in depth, not the thing
actually protecting it.

`public-page/index.php` is localized (Italian, English, French,
German — `public-page/i18n.php`). Locale priority: an explicit choice
from the flag dropdown in the page's top-right corner (a plain GET
`<form>`, `?lang=xx`, works with JavaScript disabled via a `<noscript>`
submit button) beats a remembered previous choice (`weathernet_lang`
cookie, written only when a request carries a fresh `?lang=` — never
on a plain page load) beats the visitor's `Accept-Language` header
beats English as the last-resort default. That cookie is the one
exception to `public-page/` otherwise setting no cookies at all — it's
first-party, stores nothing but the language the visitor just
explicitly picked, and exists for no purpose beyond honoring that
pick, which is the textbook "strictly necessary" exemption under
ePrivacy/GDPR (storage a user's own explicit action requested, not
tracking): it doesn't require cookie consent any more than the rest of
this page does. Translated strings needed by the map's marker popups
are passed from PHP into the page's `<script>` block the same way
`probes` itself is (`json_encode()`), so there's exactly one source of
truth (`i18n.php`) for every user-facing string, PHP-rendered or not.

**A fifth path: a Telegram bot for a daily weather digest.** Not part
of the API contract at all — this is a `subscriptions` Django app plus
a `telegram-bot` service that long-polls Telegram's Bot API
(`getUpdates`), so it needs no inbound connection to the VM whatsoever
(no webhook, and therefore no need for Telegram's servers to accept
the VM's self-signed certificate — see Section 12). Subscribing has no
web form either: a visitor opens `t.me/<bot>` (linked from
`public-page/`), presses Start, and the rest of the conversation —
giving a place name, `/list`/`/remove`/`/stop` — happens entirely
inside Telegram. Free text that isn't a command is geocoded via
Nominatim (OpenStreetMap's open geocoder, same ecosystem as the
project's map tiles — no API key) into coordinates, compared against
every active `Probe`'s location by great-circle distance, and saved as
a `WeatherSubscription` regardless of whether a probe is currently
close enough — Section 5.9 covers why, and what happens once one is.
A separate `send_daily_digest` management command, run once a day by a
systemd timer (same host-level pattern as WireGuard peer-sync,
Section 5.8), sends each qualifying subscription a summary of the
previous day's readings from whichever active probe is nearest. See
Section 5.9 for the full design.

## 4. Repository Layout

```
weathernet/
├── PROJECT_SPEC.md                # this file
├── README.md
├── .gitignore
├── server/
│   ├── docker-compose.yml
│   ├── .env.example
│   ├── nginx/
│   │   ├── nginx.conf.template     # templated with server IP at setup time
│   │   └── Dockerfile              # if custom image needed, else use official
│   ├── django_app/
│   │   ├── manage.py
│   │   ├── config/                 # Django project settings package
│   │   │   ├── settings.py
│   │   │   ├── urls.py
│   │   │   └── wsgi.py
│   │   ├── probes/                 # app: registry + enrollment
│   │   │   ├── models.py            # Probe, EnrollmentToken
│   │   │   ├── admin.py             # includes the "generate token" flow
│   │   │   ├── views.py             # POST /api/v1/enroll, GET /api/v1/public/summary
│   │   │   ├── serializers.py
│   │   │   ├── ca.py                # CSR signing helpers (uses `cryptography`)
│   │   │   ├── wireguard.py         # tunnel IP allocation + peer rendering
│   │   │   ├── aqi.py               # heuristic air quality score (shared with the Grafana panel's formula)
│   │   │   ├── management/
│   │   │   │   └── commands/
│   │   │   │       └── generate_wireguard_peers.py
│   │   │   └── migrations/
│   │   ├── telemetry/              # app: ingestion API + hypertable models
│   │   │   ├── views.py
│   │   │   ├── serializers.py
│   │   │   ├── models.py            # SensorReading / ProbeHealth (hypertables) + SensorHealthAlert (see 5.10)
│   │   │   ├── urls.py
│   │   │   ├── management/commands/
│   │   │   │   └── check_sensor_health.py  # run every 15min by a systemd timer, see 5.10
│   │   │   └── migrations/
│   │   ├── subscriptions/          # app: Telegram daily-digest bot (see 5.9)
│   │   │   ├── models.py            # WeatherSubscription
│   │   │   ├── bot.py               # command/conversation dispatch
│   │   │   ├── geocoding.py         # Nominatim wrapper
│   │   │   ├── matching.py          # nearest-active-probe lookup
│   │   │   ├── telegram_api.py      # thin Bot API wrapper (getUpdates/sendMessage)
│   │   │   ├── management/commands/
│   │   │   │   ├── telegram_bot_poll.py   # long-running: telegram-bot service's command
│   │   │   │   └── send_daily_digest.py   # run once a day by a systemd timer
│   │   │   └── migrations/
│   │   ├── requirements.txt
│   │   └── Dockerfile
│   ├── grafana/
│   │   └── provisioning/
│   │       ├── datasources/postgres.yml
│   │       └── dashboards/          # one example dashboard JSON
│   ├── scripts/
│   │   ├── setup.sh
│   │   ├── deploy.sh
│   │   ├── send-daily-digest.sh                    # docker compose exec wrapper -- see 5.9
│   │   ├── weathernet-daily-digest.service/.timer  # installed by setup.sh once TELEGRAM_BOT_TOKEN is set
│   │   ├── check-sensor-health.sh                  # docker compose exec wrapper -- see 5.10
│   │   └── weathernet-sensor-health.service/.timer # installed by setup.sh once TELEGRAM_BOT_TOKEN + TELEGRAM_ALERT_CHAT_ID are set
│   ├── pki/
│   │   ├── generate-ca.sh           # run once at server setup
│   │   └── generate-server-cert.sh  # run once at server setup
│   └── wireguard/
│       ├── generate-server-keys.sh  # run once at server setup
│       ├── sync-peers.sh            # run periodically by a host-level timer
│       └── wg0.conf.header          # static [Interface] block template
├── probe/
│   ├── weathernet_probe/
│   │   ├── __init__.py
│   │   ├── main.py                 # daemon entrypoint / main loop
│   │   ├── config.py                # loads probe config YAML
│   │   ├── health.py                # CPU/mem/disk/temperature via psutil
│   │   ├── transport.py             # mTLS HTTP client + local buffering
│   │   ├── spool.py                 # on-disk retry queue for failed sends
│   │   └── sensors/
│   │       ├── base.py              # abstract Sensor interface
│   │       ├── registry.py          # maps config names to sensor classes
│   │       └── mock.py              # MockTemperatureSensor, MockHumiditySensor, ...
│   ├── config/
│   │   └── weathernet-probe.service # systemd unit template
│   ├── requirements.txt
│   ├── scripts/
│   │   ├── setup.sh                 # takes --server / --token / --fingerprint
│   │   ├── enroll.py                # does the actual key/CSR gen + API call
│   │   └── deploy.sh
│   └── tests/
│       └── ...
├── public-page/                      # NOT part of server/ or probe/, doesn't run on the VM --
│   ├── index.php                     # visitor-facing page -- reads MySQL only, never calls the VM
│   ├── i18n.php                      # it/en/fr/de strings, detect_locale(), see below
│   ├── sync.php                      # cron entrypoint -- the only thing here that calls the VM (see 7.3/7.4)
│   ├── db.php                        # tiny PDO connection helper, shared by the two scripts above
│   ├── config.php.example            # copy to config.php -- a .php file, not a .env, see below
│   ├── schema.sql                    # the one MySQL table this needs (probe_cache)
│   ├── .htaccess                     # blocks direct URL access to config.php / *.pem / sync.php
│   └── README.md
├── 3d-printing/                       # 3D-printable enclosure/mount designs -- see 11 for licensing
│   ├── README.md                     # file-format + per-part licensing convention
│   └── stevenson_screen/             # MIT, original design (not derived from a third-party model)
│       ├── README.md
│       ├── SPS30_StevensonScreen.FCStd
│       ├── louver.step/.stl/.3mf, plate_partition.step/.stl/.3mf
│       ├── pm_body.step/.stl/.3mf, pm_lid.step/.stl/.3mf
│       └── sensor_carrier.step/.stl/.3mf, mast_bracket.step/.stl/.3mf
└── docs/
    └── api-contract.md              # formal request/response schema
```

## 5. Server Component

### 5.1 Docker Compose services

- `postgres` — use the `timescale/timescaledb` image (a standard Postgres
  image with the TimescaleDB extension pre-installed; pick a tag matching
  a current Postgres major version, e.g. `timescale/timescaledb:latest-pg16`)
  instead of the plain `postgres` image. It is a drop-in replacement as far
  as Django's `django.db.backends.postgresql` is concerned — Django doesn't
  need to know the extension is there. Serves both Django's own tables
  (auth, admin, `probes`) and the `telemetry` app's hypertables. Named
  volume for persistence. Not published to the host; only `django` (for
  reads/writes) and `grafana` (for reads) need to reach it internally.
- `django` — Django app served via gunicorn. Not published to the host;
  only reachable from `nginx` over the compose-internal network. Has the
  CA's certificate **and private key** bind-mounted read-only from
  `server/pki/` (needed to sign CSRs during enrollment — see 5.5/5.7; this
  is the one meaningful new attack-surface trade-off introduced by
  auto-enrollment, and it's called out again there deliberately). Also has
  the VM's own SSH public key bind-mounted read-only, host path
  configurable via `.env` (see 5.6/5.7) — handed to a probe during
  enrollment so the server can SSH into it without a manual key exchange.

  Implementation note on the Dockerfile: `COPY . .` runs as root, before
  the image switches to a non-root user for the final `USER` directive.
  Without an explicit `chown` of the app directory to that user in
  between, the container can't write `staticfiles/` (`collectstatic`
  fails) or anything else at runtime — this bit a real deployment, budget
  for it explicitly rather than discovering it from a permission error.
- `telegram-bot` — same image as `django`, different command
  (`manage.py telegram_bot_poll`, see 5.9). Its own service rather than
  folded into `django`'s container: it needs to run forever independently
  of gunicorn's request/response lifecycle, and a crash/restart here
  shouldn't affect the API. No PKI/SSH bind mounts (unlike `django`) --
  it only ever calls out to Telegram's API and Nominatim, and reads/
  writes its own app's table. Not published to the host either
  direction: nothing calls in, it only calls out.
- `grafana` — published on its own host port (e.g. `3000`) for the
  operator to view dashboards directly by IP. Pre-provisioned with a
  PostgreSQL datasource pointed at the same `postgres` service, and one
  example dashboard on first boot (see 5.4).
- `nginx` — the only service handling the mTLS ingestion path, and also the
  sole entry point on `443` for Django Admin (proxied straight through,
  without a client-certificate requirement -- Django's own login is the
  trust boundary there). Terminates TLS with the server's certificate.

  mTLS enforcement for `/api/v1/ingest` is done explicitly in that
  location block — an **exact match** (`location = /api/v1/ingest`), not
  a prefix. This matters: `/api/v1/enroll` must fall through to the
  unauthenticated location instead (a brand-new probe has no certificate
  yet), and a prefix match on `/api/v1/` would incorrectly catch it too.
  Enforcement is not done by nginx's SSL layer automatically: `ssl_verify_client` must
  be `optional_no_ca`, not `optional` or `on` -- plain `optional` still
  hard-rejects (with nginx's own canned response, before any location/`if`
  logic runs) any *presented* certificate that fails verification, which
  would also break serving `/admin/` unauthenticated on the same port.
  Reject with ordinary status codes checked against `$ssl_client_verify` /
  `$ssl_client_s_dn` -- not nginx's own `495`/`496`: those are internal
  pseudo-codes tied to nginx's automatic SSL enforcement, and an explicit
  `return 495`/`496` gets silently replaced with nginx's canned `400`
  page instead of actually being sent. There is also no built-in nginx
  variable for just the CN of the client certificate's subject; extract
  it from `$ssl_client_s_dn` with a regex `map` block. On success, forward
  the verified CN in a header (e.g. `X-Client-Cert-CN`) to `django`.

  `GET /api/v1/public/summary` and `GET /api/v1/public/history`
  (Section 7.3/7.4) share one `location /api/v1/public/` **prefix**
  block — a prefix, not an exact match like `/api/v1/ingest`, on
  purpose: it's what lets a new `public/*` view get the same handling
  automatically, with no nginx change, the moment its Django route
  exists. Unauthenticated like `/api/v1/enroll` (Django's own API key
  check is the trust boundary there, not nginx) but additionally behind
  an nginx `limit_req_zone` — unlike every other unauthenticated path
  here, this one has no per-request credential of its own and is
  reachable by anyone who finds the URL, so the rate limit is a real
  second layer, not just defense-in-depth theater. In practice it's a
  backstop, not the main defense against a traffic burst: the reference
  external page (`public-page/`) only ever calls this from its own
  cron job, not per visitor — see Section 3's "fourth path".

All services on one Docker network, defined in `docker-compose.yml`. Use
named volumes for `postgres` and `grafana` data so `docker compose down`
doesn't destroy data (only `down -v` should).

Note: WireGuard (Section 5.8) is deliberately **not** one of these
services. Creating a network interface (`wg0`) from inside a container
means either `--privileged` or `NET_ADMIN` plus host networking mode —
extra complexity for no real benefit here. It runs directly on the VM host
using the standard `wg-quick` tooling, alongside the Docker stack rather
than inside it.

### 5.2 Django app design

Two apps:

**`probes`** — the registry, and now also enrollment.

`Probe` model fields:
- `id` — UUID, primary key, **generated by Django when a token is
  redeemed** (not chosen by the operator or the probe). This value becomes
  the client certificate's CN.
- `name` — human-readable label, set by the operator when they create the
  enrollment token (see below), copied onto the `Probe` row when it's
  created.
- `hardware_type` — choices: `raspberry_pi_3`, `raspberry_pi_4`,
  `raspberry_pi_5`, `generic_linux` (leave room to add `arduino` later
  without a migration headache — use a `TextChoices` class, not a hardcoded
  list scattered around). Also set at token-creation time; the probe's
  enrollment script auto-detects its own hardware (Section 5.7) and sends
  it along in the enroll request purely as a sanity check against what the
  operator declared — log a warning on mismatch, don't hard-fail on it.
- `location_address` — free text, optional. A human-readable description
  of where the probe physically is (e.g. "Garden, north side of the
  house"), not a structured postal address — free text is deliberately
  good enough here, this is for an operator's own reference, not
  geocoding.
- `location_latitude`, `location_longitude` — `DecimalField(max_digits=9,
  decimal_places=6)`, both nullable/optional, entered by the operator
  (not derived from anything the probe reports — the probe itself never
  knows its own GPS position in v1). Six decimal places is sub-meter
  precision, more than this project needs but a harmless, conventional
  choice; reject out-of-range values (`-90..90` / `-180..180`) at the
  form level rather than trusting free input.
- `owner_email`, `owner_phone` — free text (an `EmailField` for the
  former), both optional at the database level so this can be added
  without breaking already-enrolled probes, but treat `owner_email` as
  the primary contact and `owner_phone` as a secondary, genuinely
  optional one when designing the Admin form (e.g. field ordering,
  helper text) — who to actually contact about a probe that's gone
  quiet or is physically in someone's way.
- `notes` — free text, optional.
- `wireguard_public_key` — text, nullable. Set automatically when the
  probe's enrollment request is processed (Section 5.7) — never entered by
  hand.
- `wireguard_tunnel_ip` — nullable, unique when set (e.g.
  `GenericIPAddressField`). Allocated automatically at enrollment time
  (Section 5.7, `wireguard.py`) — the next free address in
  `WIREGUARD_SUBNET` that isn't already assigned to another probe. This is
  *not* the probe's home/public IP — that's dynamic and irrelevant here,
  since the probe always initiates the tunnel outward.
- `is_active` — boolean, default `True`. Ingestion is rejected for inactive
  probes.
- `created_at` — auto.
- `last_seen_at` — nullable datetime, updated on every successful ingest.
- `last_health_summary` — nullable JSON field, updated on every successful
  ingest with the most recent health payload (cpu_temp_c, cpu_percent,
  mem_percent, disk_percent, uptime_seconds, undervoltage_now,
  undervoltage_occurred -- the last two from `vcgencmd get_throttled` on
  the probe, null on non-Pi hardware; see Section 7 and
  `weathernet_probe/health.py`). This lets Django Admin show
  probe health at a glance with a single indexed lookup, instead of
  querying the (much larger) hypertable for the latest row every time the
  admin list page renders.

`EnrollmentToken` model fields:
- `token_hash` — the SHA-256 hex digest of the raw token. **Never store the
  raw token** — same principle as password storage. The raw value is shown
  to the operator exactly once, at creation time, and is unrecoverable
  after that (if lost before use, the operator just generates a new one;
  tokens are free).
- `probe_name`, `hardware_type` — what the operator wants the resulting
  probe to be called and what kind of device it's for. Set at creation
  time, copied onto the `Probe` row when the token is redeemed.
- `created_at`, `expires_at` — short default lifetime (e.g. 30 minutes,
  configurable via `ENROLLMENT_TOKEN_TTL_MINUTES` in `.env`). Long enough
  for an operator to run one command, short enough that a token nobody got
  around to using stops being a live credential quickly.
- `used_at` — nullable; null means still redeemable. Set atomically (inside
  a `select_for_update()` transaction — see Section 5.7) the moment a token
  is redeemed, so a token cannot be used twice even under a race.
- `resulting_probe` — nullable FK to `Probe`, set once redeemed, so the
  admin can see which probe came from which token.

Full design for token generation and redemption is in Section 5.7 — it
touches enough (CSR signing, WireGuard IP allocation, the admin UX) that it
gets its own section rather than being buried here.

Register `Probe` in `admin.py` with a sensible `list_display` (name,
hardware_type, is_active, last_seen_at, wireguard_tunnel_ip) and
`list_filter` on `hardware_type` / `is_active`. Register `EnrollmentToken`
too, with `used_at` and `resulting_probe` in `list_display` so the operator
can see at a glance which tokens are still live. Beyond the token-creation
behavior described in 5.7, these stay close to stock `ModelAdmin` — no
custom templates.

**`telemetry`** — the ingestion endpoint.

- `POST /api/v1/ingest` — the endpoint probes call on every reporting
  cycle. See [Section 7.2](#72-post-apiv1ingest--every-reporting-cycle-mtls-authenticated) for the payload schema.
- Certificate validity is already enforced by nginx's own `/api/v1/ingest`
  location block (Section 5.1) before the request ever reaches Django — by
  the time this view runs, a valid client cert is guaranteed to have been
  presented. The view trusts the forwarded `X-Client-Cert-CN` header
  **only** because Django is not reachable except through nginx (document
  this trust boundary clearly in a code comment at the top of the view —
  this is a security-relevant assumption resting on that nginx
  configuration, not an implementation detail Django re-derives on its
  own).
- Looks up `Probe` by the CN. 404 if it doesn't exist, 403 if `is_active` is
  `False`.
- Validates the payload shape (use a `serializers.Serializer`, not raw dict
  access).
- Writes rows via the ordinary Django ORM into the two hypertables defined
  in `telemetry/models.py` (one row per reading, one row for the health
  payload — see Section 5.3 and Section 7). No separate database client
  library is needed; it's the same Postgres connection Django already has.
- Updates `last_seen_at` and `last_health_summary` on the `Probe` row.
- Returns `201` on success with an empty body; `4xx` with a short JSON error
  reason otherwise.

Use Django REST Framework if it makes the serializer/validation code
cleaner; if you'd rather avoid the extra dependency for one endpoint, a
plain Django view with manual JSON schema validation is also acceptable —
your call, but be consistent and don't half-adopt DRF.

### 5.3 TimescaleDB

Two regular Django models, promoted to hypertables via a migration:

- `SensorReading` — fields: `time` (the partitioning column), `probe`
  (FK to `Probe`), `sensor_type` (str), `value` (float), `unit` (str,
  nullable).
- `ProbeHealth` — fields: `time`, `probe` (FK), `cpu_temp_c`, `cpu_percent`,
  `mem_percent`, `disk_percent`, `uptime_seconds`, `undervoltage_now`,
  `undervoltage_occurred` (the last two nullable booleans, from
  `vcgencmd get_throttled` on the probe -- see Section 7 and
  `weathernet_probe/health.py`; added after a real incident where a
  sensor's fan startup current sagged the Pi's own 5V rail enough to
  knock it off I2C).

Implementation notes for whoever writes the migrations:

1. First migration: `CREATE EXTENSION IF NOT EXISTS timescaledb;` via
   `migrations.RunSQL`. This only needs to run once per database.
2. Let Django create the two tables normally (regular `CreateModel`
   migrations) — **do not** rely on Django's default single-column
   auto-incrementing primary key as the row identity on these tables.
   TimescaleDB hypertables partition on the time column, and a plain
   auto-increment PK works against that; either drop the PK in favor of a
   plain index strategy, or use a composite key that includes `time`. Pick
   whichever Django supports more cleanly and note the reasoning in a code
   comment — this is a real TimescaleDB-specific gotcha, not a style
   preference.
3. Follow-up migration, after the tables exist: `RunSQL` calling
   `SELECT create_hypertable('telemetry_sensorreading', 'time');` and the
   same for `telemetry_probehealth` (adjust for Django's actual generated
   table names).
4. Another `RunSQL` step enabling native compression and a compression
   policy for chunks older than a configurable age (e.g. 7 days):
   `ALTER TABLE ... SET (timescaledb.compress, timescaledb.compress_segmentby = 'probe_id');`
   followed by `SELECT add_compression_policy(...)`. This — not the choice
   of database engine — is what actually keeps disk usage in check as data
   accumulates.
5. A retention policy via `SELECT add_retention_policy(...)`, with the
   retention window configurable through `.env` (mirrors what a bucket
   retention setting would have done in a dedicated TSDB).

Indexes: at minimum, an index on `(probe_id, time DESC)` on both
hypertables to keep "latest reading per probe"-style queries (which Grafana
and the Django Admin health summary both need) fast as the tables grow.

### 5.4 Grafana

- Provision Grafana's built-in **PostgreSQL** datasource automatically via
  the `grafana/provisioning/datasources/postgres.yml` file, pointed at the
  same `postgres` service and database Django uses — the operator should
  never have to click through the UI to connect it. Grafana's PostgreSQL
  datasource understands TimescaleDB natively (it's just SQL plus the
  `$__timeFilter()` macro for the dashboard time range), no special plugin
  needed.
- Provision one example dashboard (health: last-seen timestamps and CPU
  temp per probe, queried from `telemetry_probehealth`; a placeholder panel
  for `telemetry_sensorreading` once real sensors are attached) so there's
  something to look at immediately after setup, not an empty Grafana
  instance.
- Default admin credentials come from `.env`, not hardcoded.

### 5.5 mTLS / PKI

The root of trust still has to be bootstrapped manually somewhere — that
part doesn't change. What changes from a naive design is everything
*downstream* of the CA: per-probe certificates are now issued automatically
through the enrollment flow (Section 5.7), not via a script the operator
runs by hand for every probe.

- `pki/generate-ca.sh` — run once at server setup. Creates a self-signed
  internal CA (key + cert). This CA's only job is signing probe client
  certs and the server cert; it is never meant to be trusted by browsers.
  **Must** generate it with explicit `-addext "basicConstraints=critical,CA:true"`
  and `-addext "keyUsage=critical,keyCertSign,cRLSign"`, not a bare
  `openssl req -x509`. A CA cert without an explicit `keyUsage`
  extension verifies fine with some TLS clients (plain `openssl
  s_client`, a bare `ssl.SSLContext`) and fails outright with others
  (`requests`/urllib3 -- which is what the probe uses, see
  `transport.py`) with `certificate verify failed: CA cert does not
  include key usage extension`. This was hit for real: it looked
  correct in ad hoc verification and only failed once an actual probe
  tried to authenticate. Reproduced and confirmed fixed with a bare
  `requests.get(..., verify=ca_cert)` against a throwaway TLS server
  before trusting the fix.
- `pki/generate-server-cert.sh` — generates the server's TLS cert/key,
  signed by the internal CA, **with the server's public IP as a Subject
  Alternative Name** (there is no DNS name to use — the script must take
  the IP as an argument and fail loudly if it's not provided; don't assume
  `localhost` or guess), and with an explicit `keyUsage = critical,
  digitalSignature,keyEncipherment` extension alongside
  `extendedKeyUsage = serverAuth` (for the same reason as the CA's
  `keyUsage` above -- the probe-issued client certs, signed via
  `probes/ca.py`'s `cryptography`-based signing, already set this
  correctly; only the bash+openssl-generated CA and server certs were
  missing it). Also prints the certificate's SHA-256 fingerprint
  (`openssl x509 -noout -fingerprint -sha256 -in server.crt`) — the
  operator needs this once, to give to the enrollment script for TLS
  pinning (Section 5.7).
- Per-probe certificates no longer have a standalone script. Signing
  happens inside the `/api/v1/enroll` view (`probes/ca.py`), using the
  `cryptography` package to load the CA key/cert and sign whatever CSR the
  probe submitted, with the CN forced to the newly-generated `Probe` UUID
  regardless of what (if anything) the CSR requested — the server is
  authoritative for identity assignment here, not the probe.
- Document clearly in the README that:
  1. The CA's private key never leaves the server, but — new trade-off,
     state it plainly — it **is** now readable by the `django` container
     (read-only bind mount), because that's what signs CSRs during
     enrollment. This is a deliberate convenience/exposure trade-off, not
     an oversight; see Section 5.7 for the reasoning and Section 12 for
     what a more hardened version of this would look like.
  2. Probe private keys (both the mTLS client key and the WireGuard
     private key) are generated **on the probe** and never transmitted
     anywhere, over any channel, at any point. Only the CSR (public key)
     and the WireGuard public key travel to the server.

### 5.6 Configuration

`.env.example` at `server/` covering at minimum: Postgres credentials
(shared by Django and, read-only if practical, by Grafana's datasource),
Django `SECRET_KEY` (generate a fresh one in `setup.sh`, don't ship a
default), Django `DEBUG` (must default to `False`), Django
`ALLOWED_HOSTS` (must include the server's public IP), the hypertable
retention window (e.g. `TELEMETRY_RETENTION_DAYS`, default 90) and
compression age (e.g. `TELEMETRY_COMPRESS_AFTER_DAYS`, default 7) used by
the migration that sets up the TimescaleDB policies, `WIREGUARD_SUBNET`
(default `10.10.0.0/24`) and `WIREGUARD_LISTEN_PORT` (default `51820`),
`ENROLLMENT_TOKEN_TTL_MINUTES` (default `30`), the server's own public IP
and WireGuard endpoint info (so the admin can print ready-to-use enrollment
commands — see 5.7), `SERVER_SSH_PUBLIC_KEY_HOST_PATH` (default
`/home/ubuntu/.ssh/id_ed25519.pub` — the VM's own SSH public key, bind-
mounted read-only into `django` and handed to every probe during
enrollment so the server can SSH into it without a manual step; see 5.7),
Grafana admin user/password, `PUBLIC_SUMMARY_API_KEY` (generated fresh in
`setup.sh` like the Django secret key; empty disables `GET
/api/v1/public/summary` entirely rather than leaving it open — see 7.3),
and `PUBLIC_LOCATION_PRECISION_DECIMALS` (default `2`, roughly
neighborhood-level precision — how coarsely that endpoint rounds
probe coordinates before publishing them). Also `TELEGRAM_BOT_TOKEN`
(from @BotFather, not generated by this project — empty means the
`telegram-bot` service and `send_daily_digest` both fail loudly rather
than silently doing nothing), `TELEGRAM_BOT_USERNAME` (just for
building the `t.me/<username>` link shown on `public-page/`),
`SUBSCRIPTION_MAX_DISTANCE_KM` (default `15`, see 5.9), and
`NOMINATIM_USER_AGENT` (identifies this application to Nominatim per
its usage policy — must be a real contact/project URL, not a generic
placeholder). Also `TELEGRAM_ALERT_CHAT_ID` (the operator's own
chat_id, separate from any subscriber's — empty disables the
sensor-health check entirely, see 5.10) and
`SENSOR_STALE_ALERT_MINUTES` (default `60`). `.env` itself must be
gitignored.

The server's own WireGuard keypair is **not** an env var — like the mTLS
CA, it's a generated file (`wireguard/server_private.key`,
`wireguard/server_public.key`), gitignored, with the private key never
leaving the host.

**Django settings requirements beyond `.env`**, both discovered the hard
way in an earlier pass and worth stating explicitly so they aren't lost
in a rewrite:
- `SECURE_PROXY_SSL_HEADER = ("HTTP_X_FORWARDED_PROTO", "https")` is
  required, not optional, given nginx terminates TLS and proxies to
  Django over plain HTTP internally. Without it, `request.is_secure()` is
  always `False`, and Django's CSRF `Origin` check — which compares the
  browser's real `https://...` Origin against what Django itself believes
  the scheme is — rejects every POST, including Admin login, as
  cross-origin. `SESSION_COOKIE_SECURE`/`CSRF_COOKIE_SECURE = True` should
  follow once this is set, since the admin is genuinely HTTPS-only.
- An explicit `LOGGING` setting that sends everything to a console
  handler **unconditionally**, not gated on `DEBUG`. Django's own default
  logging config only sends request-handling exceptions (i.e. anything
  that becomes a `500`) to the console when `DEBUG=True`; with
  `DEBUG=False` (required, see above) the only handler left is
  `mail_admins`, which does nothing without `ADMINS` configured. Left at
  the default, `docker compose logs django` shows gunicorn's boot
  messages and nothing else, even across a real unhandled exception —
  exactly the situation where an operator most needs to see a traceback.

### 5.7 Zero-Touch Probe Enrollment

This is the mechanism that replaces manual UUID assignment, manual cert
issuance + `scp`, and manual WireGuard key exchange with a single
token-based exchange. It's the most security-sensitive piece of new
surface in the project, so read it carefully before implementing — the
shape matters more than the exact code.

**Generating a token (operator, in Django Admin):**

1. Operator opens `EnrollmentToken` in Django Admin and adds a new one,
   filling in `probe_name` and `hardware_type` (and optionally overriding
   the default expiry).
2. `admin.py` overrides `save_model()`: on create, generate a random,
   high-entropy token (`secrets.token_urlsafe(32)` or similar), store only
   its SHA-256 hash on the model, and — this is the only place the raw
   token ever exists outside the operator's terminal — surface it via
   `self.message_user(...)` on the resulting admin page, formatted as a
   ready-to-paste shell command:
   ```
   Token (shown once): 3f7a1c9e...
   Run on the probe (after `git clone`-ing this repo):
     ./probe/scripts/setup.sh \
       --server <server-public-ip> \
       --token 3f7a1c9e... \
       --fingerprint <server-cert-sha256-fingerprint>
   ```
   The server IP and fingerprint come from settings/`.env`, not typed by
   the operator each time.

**Redeeming a token (probe, one command):**

`probe/scripts/setup.sh --server ... --token ... [--fingerprint ...]`
does, via `probe/scripts/enroll.py`:

1. Installs OS packages (Python venv, `wireguard-tools`) if missing.
2. Auto-detects hardware type where possible (Raspberry Pi model is
   readable from `/proc/device-tree/model` or `/proc/cpuinfo` — use that
   to distinguish Pi 3/4/5; fall back to `generic_linux` if detection is
   inconclusive, don't guess wrong silently).
3. Generates the mTLS client keypair and a CSR **locally** (the private
   key never leaves this step). Generates the WireGuard keypair **locally**
   the same way.
4. If `--fingerprint` was given: opens a TLS connection to
   `https://<server>/`, reads the presented certificate's SHA-256
   fingerprint, and aborts loudly if it doesn't match before sending
   anything. If `--fingerprint` was omitted: proceeds without pinning, but
   prints a clear warning that it's doing so — this is a real reduction in
   the guarantee, not a silent one.
5. `POST /api/v1/enroll` with the token, the CSR (PEM), the WireGuard
   public key, and the detected hardware type. See Section 7 for the exact
   schema.
6. On success, writes everything the response contains to disk: the signed
   client cert, the CA cert, `probe.yaml` (assigned `probe_id`,
   `hardware_type`, `server_url`, cert/key paths, default
   `report_interval_seconds`), and `wg0.conf` (this probe's tunnel IP as
   `Address`, the private key just generated, one `[Peer]` block for the
   server using the server's WireGuard public key + endpoint from the
   response, `PersistentKeepalive = 25` since the probe is almost
   certainly behind a home NAT with no port forwarding).
7. If the response includes the server's SSH public key (it's optional
   server-side — see below), append it to the enrolling user's own
   `~/.ssh/authorized_keys` (create `~/.ssh` with `0700` if it doesn't
   exist, the file itself `0600`, skip appending if that exact key line
   is already present). `setup.sh` invokes `enroll.py` with
   `--ssh-user <the user running setup.sh>` so it knows whose home
   directory to write into even though it runs elevated (it needs root to
   write `/etc/weathernet-probe` and `/etc/wireguard`; resolve the
   target user's home directory server-side via `pwd.getpwnam()`, don't
   assume `$HOME`, which under `sudo` would resolve to root's). This is
   what lets the server SSH straight into a newly enrolled probe with no
   manual key copying at all — see 5.8/6.7.
8. Installs and starts both `weathernet-probe.service` and
   `wg-quick@wg0.service`.
9. Prints a plain confirmation: probe ID, tunnel IP, and "you should see
   this probe appear in Grafana within `report_interval_seconds`, and it
   should be SSH-reachable at `<tunnel-ip>` from the server within about a
   minute" (see the sync timer note below) — and, if the server's SSH key
   was installed, "the server can already SSH in directly, no key setup
   needed."

**Server-side enrollment view (`probes/views.py`, `POST /api/v1/enroll`):**

1. Hash the incoming token, look up `EnrollmentToken` by `token_hash`
   inside `transaction.atomic()` with `select_for_update()` — this makes
   the "is it unused and unexpired" check and the "mark it used" write
   atomic, so a token can't be redeemed twice via a race (e.g. the probe's
   script retries a request that actually succeeded server-side but whose
   response got lost).
2. Reject with `404` if no token matches the hash, `410` if it's expired
   or already used — distinct codes so the probe-side script can print a
   sensible message instead of a generic failure.
3. Generate a new `Probe` UUID, sign the submitted CSR via `probes/ca.py`
   (loads the CA key/cert from the mounted `pki/` files, sets the CN to the
   new UUID regardless of what the CSR requested, sets a reasonable
   validity period — years, not the token's own short lifetime, since
   there's no rotation flow yet per Section 12), and allocate the next free
   `wireguard_tunnel_ip` in `WIREGUARD_SUBNET` via `probes/wireguard.py`
   (query existing non-null tunnel IPs, pick the lowest unused one, `409`
   if the subnet is exhausted rather than silently colliding).
4. Create the `Probe` row with all of the above plus the submitted
   `wireguard_public_key`.
5. Mark the token `used_at = now()`, `resulting_probe = <the new probe>`.
6. Respond `201` with: the signed client cert (PEM), the CA cert (PEM),
   the assigned `probe_id`, the assigned `wireguard_tunnel_ip`, the
   server's WireGuard public key, the server's WireGuard endpoint
   (`<public-ip>:<port>`), the server's own WireGuard *tunnel* address
   (e.g. `10.10.0.1` — not the same thing as the public endpoint above;
   this is what the probe's own `[Peer]` block's `AllowedIPs` must be),
   and the contents of the server's SSH public key from
   `SERVER_SSH_PUBLIC_KEY_HOST_PATH` if that file is readable (`null` if
   not — this is a best-effort convenience, not something that should
   ever fail enrollment). See Section 7 for the exact JSON shape.

**Ordering within the view, stated as a rule, not just an example:**
gather and validate *everything* the response needs — signing the CSR,
allocating the tunnel IP, reading the CA cert and the SSH public key file
back off disk — before the `Probe`/`EnrollmentToken` writes inside the
`transaction.atomic()` block, not just before the writes that obviously
depend on that data. A failure raised after those writes commit but
before the response is returned leaves a burned token and an orphaned
`Probe` row with no certificate ever delivered to the device — a real
failure mode hit during implementation (a file-permissions slip on the
WireGuard public key), not a hypothetical one. If a future revision adds
another field to the response, the same ordering applies to it too.

**Applying the new WireGuard peer:** the enrollment view runs inside the
`django` container and, same constraint as always, has no host-level
network privileges to run `wg syncconf` itself. Rather than trying to
bridge that gap from an unprivileged web process (which would mean either
running Django as a more privileged process or building some kind of
privileged helper socket — real complexity for marginal benefit here), a
plain **host-level systemd timer runs `wireguard/sync-peers.sh` once a
minute**. A newly enrolled probe's peer becomes active within that window
without the operator doing anything — this also quietly closes the
"automatic peer sync" gap that a purely-manual design would have left
open, without needing to give the web app privileged host access to do it
synchronously.

**Why the CA key living in the `django` container is an acceptable
trade-off here, stated plainly:** the alternative is either (a) keep
issuance fully manual, which is the exact friction this section exists to
remove, or (b) build a separate, minimal signing service that Django calls
over some other channel — strictly better isolation, but real additional
infrastructure for a project whose entire premise is "a handful of home
weather stations." For v1, mounting the key read-only into a container
that's itself not directly internet-reachable (only nginx is) is a
reasonable point on that trade-off curve. It is still a trade-off, not a
non-issue — Section 12 revisits what a hardened version would look like.

### 5.8 Remote Access via WireGuard (Ongoing Operation)

Enrollment (5.7) is how a probe *gets* WireGuard access; this section is
about the tunnel once it exists — see the diagram and rationale in
Section 3.

**Server side, once, at server setup time (unchanged from before):**

1. `wireguard/generate-server-keys.sh` generates the server's keypair.
   The public key ends up in `.env`/settings so the enrollment response
   (5.7) and the admin's printed setup command can both reference it
   without a human copying it around. The private key needs restrictive
   permissions (`umask 077` before generating it is fine) — but don't let
   that umask also restrict the **public** key file: it's not sensitive,
   it's read by the `django` container (a different host UID than
   whichever user ran this script) and handed to every probe, so it needs
   to end up world-readable (`chmod 644` after generating it), not
   inheriting the private key's `600`.
2. `wg-quick up wg0` is brought up on the host directly (not in Docker —
   see the note in 5.1), listening on `WIREGUARD_LISTEN_PORT`, with its own
   tunnel address `10.10.0.1` (the first address in `WIREGUARD_SUBNET`).
3. The VM's firewall / cloud security group needs the WireGuard UDP port
   opened, in addition to `443` for nginx and Grafana's port — call this
   out explicitly in the setup script's summary output, since it's easy to
   forget and the failure mode (tunnel silently doesn't come up) is
   confusing to debug. When troubleshooting this, check the *actual*
   firewall tool in use (`sudo iptables -L INPUT -n -v` /
   `sudo nft list ruleset`), not just `ufw` — it may not even be
   installed. Several cloud providers sync a local `iptables`/`nftables`
   ruleset automatically from the provider's own console/API (a security
   group), in which case a rule added directly on the host is only a
   test, not a durable fix; the persistent one is opening the port in
   that console. `sudo tcpdump -i any udp port $WIREGUARD_LISTEN_PORT -n`
   on the server while a probe's keepalive is retrying is the fastest way
   to tell "packets never arrive" (upstream block) from "packets arrive
   but no handshake" (local firewall dropping them after arrival).
4. Install the systemd timer that runs `wireguard/sync-peers.sh` every
   minute (a small `.timer` + `.service` unit pair, or a root crontab entry
   if you'd rather skip the extra unit files — either is fine, pick
   whichever the setup script can install more simply).

**Peer configuration, maintained automatically by `sync-peers.sh`:** each
peer stanza's `AllowedIPs` is that probe's tunnel IP as a single `/32` —
not the whole subnet. WireGuard doesn't bridge peers to each other unless
you configure it to; keeping each `AllowedIPs` scoped to one `/32` means
this stays strictly hub-and-spoke (server ↔ each probe), with no probe able
to reach another probe through the server even if it wanted to. The
`generate_wireguard_peers` management command includes **inactive** probes
in the peer list too — `is_active` on `Probe` gates *telemetry ingestion*,
not SSH reachability. A probe you've deactivated because its sensors are
misbehaving is exactly the probe you most want to still be able to SSH
into. Don't wire these two flags together.

**Implementation trap in `sync-peers.sh` worth flagging explicitly:**
applying the freshly-rendered config to a live interface needs
`wg syncconf`, which needs its input already reduced to what `wg-quick
strip` produces. The natural-looking way to chain this —
`sudo wg syncconf wg0 <(sudo wg-quick strip wg0.conf)` — routinely fails
with `fopen: No such file or directory`. Piping a process-substitution
`/dev/fd/N` path through a *second*, outer `sudo` breaks because sudo
commonly closes inherited file descriptors above stderr before exec'ing
its target, as a security default. Write to a real temp file instead
(`sudo wg-quick strip wg0.conf > tmpfile` as one step, `sudo wg syncconf
wg0 tmpfile` as the next) — a real path has no fd-inheritance edge case.
Since this script runs under `set -euo pipefail` and is called
unconditionally from `setup.sh`'s WireGuard step, a failure here doesn't
just skip the peer sync — it aborts the rest of `setup.sh` too, including
whatever comes after (in v1's ordering, that's the systemd timer
installation). A script dying partway through under `set -e` can look
like an unrelated later step "was never implemented" when it was actually
just never reached — worth remembering when diagnosing which of two
symptoms is the real cause.

**Reaching a probe:** the operator SSHes into the server (existing access,
unrelated to any of this), then from there `ssh <user>@10.10.0.x` to the
probe's tunnel address. The server acts as a bastion; the operator's own
laptop does not need to be a WireGuard peer for v1 (see Section 12 for the
option to add that later). Since enrollment (5.7) installs the server's
own SSH public key into the probe's `authorized_keys` automatically, this
should just work with no key setup on the operator's part — the earlier
design (before that automatic install existed) required either copying
the server's key to the probe by hand, or forwarding the operator's own
laptop-side agent through the server with `ssh -A` for the hop. Agent
forwarding is still the right fallback if `SERVER_SSH_PUBLIC_KEY_HOST_PATH`
wasn't configured, doesn't resolve, or the probe was enrolled before this
feature existed.

### 5.9 Telegram Daily Digest (`subscriptions` app)

A `WeatherSubscription` (chat id + a geocoded place + coordinates) lets
someone receive a once-a-day summary of the previous day's readings
from whichever active probe is nearest to a place they name — entirely
through a Telegram bot, with no web form (Section 3's "fifth path").
Why a bot conversation instead of a form asking for a phone number,
which is how this was first proposed: Telegram's Bot API has no way to
message an arbitrary phone number — a bot can only message a chat that
already exists, i.e. one where a user pressed Start. There is no
number to type at all in the working design; the chat itself, once
started, is the identity.

**Bot process (`telegram-bot` service, `manage.py telegram_bot_poll`,
5.1).** Long-polls Telegram's `getUpdates` (25s per call) rather than
running a webhook — a webhook would need Telegram's servers to accept
an inbound HTTPS connection to the VM, and the VM's certificate is
self-signed (Section 12), not something to route around just for this.
Runs forever as its own container process, not a cron job, so replies
feel immediate rather than up-to-a-timer-interval delayed. Dispatch
(`subscriptions/bot.py`) is deliberately separate from the poll loop
itself so it's unit-testable without a live network connection (mock
`send_message`, call the dispatch function directly).

**Conversation, driven entirely by free text plus four commands:**
- `/start` / `/help` — welcome/instructions.
- Any other text — treated as a place name (rejected outright above
  `MAX_QUERY_LENGTH`, 200 chars — see "Abuse resistance" below).
  Geocoded via Nominatim (OpenStreetMap's open geocoder — no API key).
  Doesn't need to be precise, only close enough to compare against
  probe locations. A repeat query resolving within ~1km of an existing
  subscription for the same chat is treated as a duplicate, not a new
  one, to avoid silent pile-up from re-sending roughly the same place
  name.
- `/list` — every subscription for this chat, each annotated with its
  current nearest-probe distance (or "none close enough yet").
- `/remove <n>` — remove the nth subscription (the number shown by
  `/list`).
- `/stop` — remove every subscription for this chat.

A chat may have more than one subscription (e.g. home and a holiday
house), each tracked and matched independently.

**Matching (`subscriptions/matching.py`).** Great-circle (haversine)
distance from a subscription's coordinates to every active `Probe`
with coordinates set; the nearest one, regardless of distance, is
returned, and callers compare it against `SUBSCRIPTION_MAX_DISTANCE_KM`
(default 15) themselves. No spatial index — a linear scan over a
handful of probes is fine at this project's scale. Recomputed on every
`/list` and every digest run rather than pinned to a probe at
subscribe time: a closer probe enrolled later, or the current one
deactivated, should change the answer without the subscriber doing
anything.

If a subscription's coordinates aren't within range of any active
probe at subscribe time, it's saved anyway, with the bot saying so
explicitly — not silently dropped, and not treated as an error. Once a
probe *is* within range (either at subscribe time, or in a later
`send_daily_digest` run — see below), `WeatherSubscription.probe_ever_found`
flips permanently to `True`.

**Daily digest (`send_daily_digest`, run once a day by
`weathernet-daily-digest.timer`/`.service`, same host-level
systemd-timer-runs-`docker compose exec` pattern as WireGuard
peer-sync, Section 5.8/8.1).** For every subscription with an active
probe within range: query `SensorReading` for that probe over
*yesterday*, computed as a calendar day in the server's local timezone
(`settings.TIME_ZONE`, Section 5.6) rather than a UTC day boundary, so
"yesterday" means what a reader intuitively expects. Aggregate
min/max/avg temperature, avg humidity, min/max/avg pressure, and the
same heuristic air quality score used elsewhere (`probes/aqi.py`,
Section 7.3) from avg gas resistance against a 7-day rolling baseline.
Temperature/humidity/pressure use the same chip-fallback policy as the
public API (`probes/sensor_fallback.py`, shared by both rather than
duplicated): BME680's generic `sensor_type` is preferred when a probe
has it, falling back to BMP280/HTU21D-F's chip-prefixed ones so a probe
without BME680 still gets a real digest instead of every field reading
"n/d". No fallback exists for the gas/AQI figure -- there's no
equivalent sensor on the fallback chips. Missing data for any one field
renders as "n/d" in the message rather than failing the whole send. The **first** time a subscription's
`probe_ever_found` flips to `True` during a digest run, the message
gets an extra "a probe is now in range" line ahead of the regular
summary — the alert the original feature request specifically asked
for, not just a silent start. A subscription with no probe in range is
skipped entirely for that day: not an error, just not ready yet.

**Abuse resistance.** Long-polling already means there's no inbound
network endpoint to attack (Section 12) — the only surface is Telegram
messages, which anyone can send to a public bot at any rate Telegram
itself allows, accidentally or as a deliberate DoS attempt. Two
concrete failure modes that come from that, both mitigated in
`subscriptions/geocoding.py` and `bot.py` rather than left as a
documented-but-unenforced policy:
- **Getting this server's IP blocked by Nominatim.** Its usage policy
  caps requests at 1/second; a message flood would blow past that in
  a real client. `geocoding.py` enforces the same cap itself, in
  process (`_throttle()`, a module-level last-request timestamp) —
  every call to `geocode_place()` blocks until at least 1.1s have
  passed since the previous one, regardless of how fast messages
  arrive. Getting Nominatim to block this server would break geocoding
  for every legitimate user, not just whoever triggered it, which is
  why this is enforced rather than just documented as a policy to
  respect.
- **Unbounded growth from one chat.** The Nominatim throttle slows a
  flood down but doesn't cap how many subscriptions eventually land
  from a patient sender. `MAX_SUBSCRIPTIONS_PER_CHAT` (10) and
  `MAX_QUERY_LENGTH` (200 chars) in `bot.py` bound both the table's
  growth and the number of digest messages one chat can generate per
  day — both checked *before* geocoding, so a rejection never costs a
  wasted (throttled) Nominatim call.

Both limits are conservative, hardcoded constants rather than `.env`
settings — there was no reason to expose a knob for numbers this
generous relative to legitimate use. A determined, sustained attack
(many different Telegram accounts, each under both limits) is not
defended against beyond what's above; not worth more machinery at this
project's scale, but worth being honest that these two limits raise
the bar rather than eliminate the risk entirely.

### 5.10 Sensor-Health Alerts (`telemetry` app)

An operational alert, not a subscriber feature: one fixed Telegram
recipient (`TELEGRAM_ALERT_CHAT_ID`, the operator's own chat_id — get
it from @userinfobot or similar) gets a message when a sensor stops
reporting fresh data, reusing the same bot/`send_message()` as the
daily digest (5.9) but never fanned out to `WeatherSubscription`s.

**Detection (`check_sensor_health`, run every 15 minutes by
`weathernet-sensor-health.timer`/`.service`, same
systemd-timer-runs-`docker compose exec` pattern as the digest).** For
every active probe, for every `sensor_type` it has *ever* reported: if
its single most recent `SensorReading` is older than
`SENSOR_STALE_ALERT_MINUTES` (default 60 — deliberately well past the
probe's `report_interval_seconds` plus however long a normal network
blip takes to clear the probe's own offline spool, 6.4, so a routine
hiccup never alerts), send one alert message and record it
(`SensorHealthAlert`, one row per open alert) so the same failure
doesn't re-alert every run. The moment that `sensor_type` reports
again, send a "recovered" message and delete the row. Deactivating a
probe clears any alert left open for it silently (no recovery
message) rather than leaving it unresolved forever.

**Deliberately one mechanism for two symptoms.** "A sensor stopped
working" and "a sensor's reading went out of range" are not
distinguished here: every real driver already rejects an implausible
reading before it's ever sent (5.2's sibling change to `probe/`, listed
in 6.2), so from the server's point of view both failure modes look
identical — no fresh reading for that `sensor_type`. A probe-wide
outage (WiFi down, server down for maintenance) surfaces the same way,
as every one of that probe's sensor types going stale at once — not a
separate case, and not something this alert needs to resolve itself:
the probe's own spool (6.4) already replays the backlog once
connectivity returns, so recovery is automatic once the underlying
problem clears.

**Known limitation.** Only `sensor_type`s that have reported at least
once for a given probe within the last 30 days are checked (a
performance bound on the aggregate query, not a configurable setting)
— a sensor that has *never* once reported since a probe was enrolled
can't be distinguished from "not installed on this probe" and is
silently not alerted on.

## 6. Probe Component

### 6.1 Design constraints

- No containerization. Plain Python 3, a virtualenv, and a systemd service.
  Assume Raspberry Pi OS (current stable, Debian-based) as the target OS for
  v1, but don't hardcode Raspberry Pi OS paths where a generic Linux
  assumption would do just as well — the goal is "runs on a Pi today,
  doesn't fight you on a generic Debian box tomorrow."
- Must run comfortably on a Raspberry Pi 3 — keep dependencies light.
  `psutil` for health metrics is fine; avoid pulling in heavy frameworks.
  In practice `psutil` almost always has no prebuilt wheel for a Pi's
  exact Python-version/architecture combination and compiles its C
  extension from source on install — `probe/scripts/setup.sh` must
  install `python3-dev` and `build-essential` (via the system package
  manager) before `pip install`, or that build fails outright with a
  missing-`Python.h` error. This isn't optional/defensive, it's the
  expected path on real Pi hardware, not an edge case.
- Single long-running process managed by systemd (`Restart=on-failure`),
  not a cron/systemd-timer firing a fresh process each cycle — simpler to
  reason about for connection reuse and in-memory buffering state.

### 6.2 Pluggable sensor framework

This is the most important structural piece of the probe for future-proofing.

- `sensors/base.py` defines an abstract `Sensor` class with at least:
  `sensor_type` (str identifier, e.g. `"temperature_c"`), and a `read()`
  method returning a numeric value (or raising a well-defined exception on
  read failure — a failed sensor must not crash the whole reporting cycle).
- `sensors/mock.py` implements a small set of mock sensors (e.g.
  `MockTemperatureSensor`, `MockHumiditySensor`, `MockPressureSensor`) that
  return plausible randomized values, useful on a probe with no real
  sensor wired up yet. Real drivers now exist alongside them for BME680,
  BMP280, HTU21D-F, and SPS30 (`sensors/bme680.py`, `bmp280.py`,
  `htu21d.py`, `sps30.py` — see the README's wiring section for each). A
  wind vane/anemometer and a rain gauge are still **explicitly
  deferred** — see Section 12.
- **Every real driver validates its own reading against a plausible
  range before returning it**, raising `SensorReadError` (same failure
  path as "sensor unreachable" — see 6.4/6.5) rather than passing a
  corrupted value through. Real incident this guards against: a
  corrupted SPS30 UART frame once unpacked into tens of thousands of
  µg/m³ across all four PM channels, spiking the Grafana chart before
  anyone noticed. Each driver sources its bound honestly rather than
  guessing: chip datasheet operating range for temperature/pressure/
  humidity (BME680, BMP280, HTU21D-F — the last one padded a few
  points past 0/100% for a known, legitimate formula overshoot right at
  the physical extremes, distinct from actual corruption), Sensirion's
  own 0-1000 µg/m³ mass-concentration spec for SPS30, and a documented
  pure sanity floor/ceiling (not a calibrated range) for BME680's
  uncalibrated gas resistance.
- `sensors/registry.py` maps a string name (as it appears in the probe's
  YAML config) to a `Sensor` subclass, so which sensors are "active" on a
  given probe is a config change, not a code change. Adding a real driver
  later means adding one module and one registry entry — nothing else in
  `main.py` or `transport.py` should need to change.
- The probe's YAML config lists which sensors to instantiate by name (see
  6.6). This is also where hardware-type-specific behavior hooks in: the
  registry/config combination is the extension point for a future Arduino
  gateway mode, not a separate code path bolted on elsewhere.

### 6.3 Health metrics (real implementation, not mocked)

Implement for real using `psutil` plus reading the Pi's thermal zone file
(`/sys/class/thermal/thermal_zone0/temp`) for CPU temperature, with a
fallback (log a warning, report `null`) if that path doesn't exist on a
non-Pi host. Report: CPU temperature (°C), CPU utilization (%), memory
utilization (%), disk utilization (%) of the root filesystem, and process
uptime (seconds since the daemon started). This is infrastructure-level
telemetry, independent of the mock/real sensor decision above — it must be
genuinely functional in v1, since it's what an operator would actually use
to notice a probe in distress.

### 6.4 Transport and local buffering

- `transport.py` builds an `https` client (Python's `requests` with
  `cert=(client_cert_path, client_key_path)` and `verify=<path to CA cert>`
  — do **not** disable certificate verification anywhere, including for the
  server's own cert; the probe must verify the server just as the server
  verifies the probe).
- On send failure (network error, non-2xx response, timeout), do not drop
  the reading: append it to a local on-disk spool
  (`spool.py` — a simple append-only JSON-lines file is sufficient, no need
  for a database on the probe side) and retry on the next cycle, oldest
  first, with a sane cap on spool size so a long outage doesn't fill the
  SD card (e.g. cap at N days worth of readings at the configured interval,
  drop oldest beyond that, and log when this happens).
- This matters: these devices are meant to run outdoors, unattended, for
  months. A flaky connection should degrade to "data delayed" not "data
  lost."

### 6.5 Main loop

`main.py`: load config → instantiate configured sensors from the registry →
loop forever at the configured interval → read all sensors (catching and
logging per-sensor failures without aborting the cycle) → read health
metrics → attempt to flush the spool, then send the current reading →
sleep. Use Python's `logging` module with a rotating file handler, not
bare `print()`.

### 6.6 Probe configuration file

`probe.yaml` — written automatically by `probe/scripts/enroll.py` at the
end of the enrollment flow (Section 5.7), not hand-templated by the
operator. Contains: `probe_id` (assigned by the server), `hardware_type`,
`server_url` (built from the `--server` argument), paths to the client
cert/key/CA cert (also written by `enroll.py`), `report_interval_seconds`
(a sane default; the operator can edit it after the fact), and the list of
enabled sensor names matching entries in `sensors/registry.py` (default:
all the mock sensors, so there's something to see in Grafana immediately).

A `config/probe.example.yaml` documenting the schema is still worth
shipping for reference/manual editing later, but it is not part of the
normal setup path anymore.

**`enroll.py` must also clear the spool (`spool_path`, default
`/var/lib/weathernet-probe/spool.jsonl`) as part of every enrollment,
including a re-enrollment of an already-set-up probe.** Every spooled
entry carries its own `probe_id`, fixed at the moment it was queued. A
(re-)enrollment always assigns a *new* `probe_id`, so any entry already
in the spool becomes permanently unsendable the instant enrollment
finishes -- the server 403s a `probe_id`/certificate mismatch (Section
7.2), and there is no way to make it match again, the certificate that
could have matched it was just overwritten. This is worse than it
sounds: `transport.py` sends the spool oldest-first and stops at the
first failure (Section 6.4), so leaving stale entries in place doesn't
just waste retries on those entries -- it permanently blocks *every*
subsequent reading too, since they can never get past the stuck stale
entry at the front of the queue. Hit for real during a routine
re-enrollment: the probe looked healthy (valid cert, WireGuard up) but
`last_seen_at` never updated, and the actual cause (spool blocked on
stale entries) was one layer behind the first error the logs showed.

### 6.7 WireGuard setup on the probe

Folded into `probe/scripts/enroll.py` as of Section 5.7 — there's no
separate manual WireGuard step anymore. For reference, what the script
does at the OS level (no new code under `weathernet_probe/`, just
`wireguard-tools` and a config file):

1. Install `wireguard-tools` via the system package manager, if missing.
2. Generate the keypair locally as part of the same step that generates
   the mTLS CSR (Section 5.7) — the private key never leaves the device,
   permissions locked down to root-readable-only.
3. Once the enrollment response comes back with the assigned tunnel IP,
   the server's WireGuard public key, and the server's endpoint, render
   `/etc/wireguard/wg0.conf`: `Address` = this probe's assigned tunnel IP,
   `PrivateKey` = the one generated in step 2, one `[Peer]` block for the
   server (`AllowedIPs` = the server's tunnel IP as a `/32`,
   `PersistentKeepalive = 25` — necessary since the probe is almost
   certainly behind a home NAT with no port forwarding; without a
   keepalive the NAT mapping will time out and the server won't be able to
   re-initiate the connection).
4. `systemctl enable --now wg-quick@wg0`.
5. If the enrollment response included the server's SSH public key,
   append it to the enrolling user's `~/.ssh/authorized_keys` (see
   5.7 step 7 for the exact mechanics, including why `enroll.py` needs
   an explicit `--ssh-user` rather than trusting `$HOME` while running
   elevated). This is what makes the server able to SSH straight into
   the probe with zero manual key setup once the tunnel is up.
6. As defense in depth (the tunnel is already only reachable by the
   authenticated server peer, but a compromised server or a
   misconfiguration shouldn't hand over more than necessary): configure the
   probe's local firewall to only accept SSH on the `wg0` interface, nothing
   else. A couple of `ufw` rules are enough; don't over-engineer this.

## 7. API Contract

Document this formally in `docs/api-contract.md` as well as implementing
it; keep the two in sync. Four endpoints, with different trust models —
see Section 5.1 for how nginx handles the difference at the TLS layer.

### 7.1 `POST /api/v1/enroll` — one-time, unauthenticated by cert

No client certificate involved (the probe doesn't have one yet). Trust
comes entirely from the token.

Request body:
```json
{
  "token": "3f7a1c9e-...-raw-token-value",
  "csr_pem": "-----BEGIN CERTIFICATE REQUEST-----\n...",
  "wireguard_public_key": "base64-wg-pubkey==",
  "detected_hardware_type": "raspberry_pi_4"
}
```

Response `201`:
```json
{
  "probe_id": "b3f2c1a0-....",
  "client_cert_pem": "-----BEGIN CERTIFICATE-----\n...",
  "ca_cert_pem": "-----BEGIN CERTIFICATE-----\n...",
  "server_url": "https://<server-public-ip>",
  "wireguard": {
    "tunnel_ip": "10.10.0.5",
    "server_public_key": "base64-server-wg-pubkey==",
    "server_endpoint": "<server-public-ip>:51820",
    "server_tunnel_ip": "10.10.0.1"
  },
  "server_ssh_public_key": "ssh-ed25519 AAAA... ubuntu@weather",
  "report_interval_seconds": 60
}
```

`wireguard.server_endpoint` (public IP:port, for `Endpoint =`) and
`wireguard.server_tunnel_ip` (this server's own WireGuard address, for
this probe's `AllowedIPs =`) are two different addresses — a response
missing one of them because it looked redundant with the other is a real
mistake this project's own implementation made once already. `server_ssh_public_key`
is `null` when `SERVER_SSH_PUBLIC_KEY_HOST_PATH` isn't configured or
isn't readable — a missing SSH key must never fail enrollment itself,
it's a convenience layered on top, not a requirement of it.

Responses: `201` as above on success; `400` malformed payload or invalid
CSR; `404` token hash doesn't match any token; `410` token expired or
already used; `409` WireGuard subnet exhausted (extremely unlikely at this
project's scale, but handle it instead of crashing).

### 7.2 `POST /api/v1/ingest` — every reporting cycle, mTLS-authenticated

By the time a request reaches this view, nginx's `/api/v1/ingest` location
block has already rejected anything without a valid client certificate
(Section 5.1) — this endpoint only ever sees pre-authenticated requests.

Request headers (set by nginx, not the probe — see Section 5.1):
```
Content-Type: application/json
X-Client-Cert-CN: <set by nginx from the verified client certificate>
```

Request body:
```json
{
  "probe_id": "b3f2c1a0-....",
  "timestamp": "2026-08-17T14:32:00Z",
  "readings": [
    {"sensor_type": "temperature_c", "value": 21.4},
    {"sensor_type": "humidity_pct", "value": 55.2}
  ],
  "health": {
    "cpu_temp_c": 48.1,
    "cpu_percent": 12.5,
    "mem_percent": 34.0,
    "disk_percent": 21.0,
    "uptime_seconds": 903421,
    "undervoltage_now": false,
    "undervoltage_occurred": false
  }
}
```

`health.undervoltage_now`/`undervoltage_occurred` (from `vcgencmd
get_throttled` on the probe, `weathernet_probe/health.py`) are optional
fields, not just nullable ones — added after probes were already
reporting in the field, so a not-yet-updated probe's payload (with no
knowledge of these keys at all) must still validate rather than `400`.
`null`/absent on non-Pi hardware or if `vcgencmd` itself is unavailable.

`probe_id` in the body must match `X-Client-Cert-CN` — reject with `403` if
they differ (a probe must not be able to report data under another probe's
identity even if it somehow had a valid cert).

Responses: `201` empty body on success; `400` malformed payload; `403`
CN/body mismatch or inactive probe; `404` unknown probe.
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

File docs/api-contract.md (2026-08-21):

# API Contract

Three endpoints, with different trust models -- see `server/nginx/nginx.conf.template`
for how nginx handles the difference at the TLS layer (only `/api/v1/ingest`
requires a client certificate; `/api/v1/enroll`, `/api/v1/public/summary`,
and `/admin/` share the same port without one).

Keep this document in sync with `server/django_app/probes/serializers.py`
/ `views.py` and `server/django_app/telemetry/serializers.py` / `views.py`.

## `POST /api/v1/enroll`

One-time, **not authenticated by client certificate** -- a brand-new
probe doesn't have one yet, that's the problem this endpoint exists to
solve (see `PROJECT_SPEC.md` Section 5.7). Trust comes entirely from a
short-lived, single-use token created in Django Admin.

### Request body

```json
{
  "token": "3f7a1c9e-...-raw-token-value",
  "csr_pem": "-----BEGIN CERTIFICATE REQUEST-----\n...",
  "wireguard_public_key": "base64-wg-pubkey==",
  "detected_hardware_type": "raspberry_pi_4"
}
```
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

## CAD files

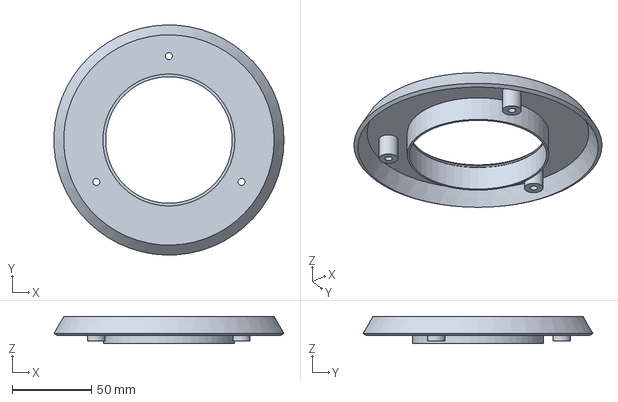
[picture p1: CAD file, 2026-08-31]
3d-printing/stevenson_screen/louver_top.step
145.4 x 145.5 x 17.2 mm

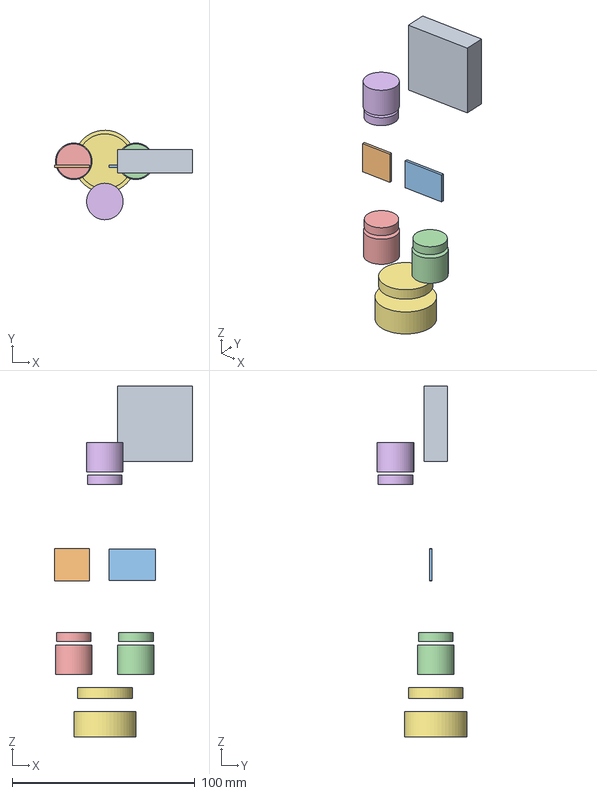
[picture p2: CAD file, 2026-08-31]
3d-printing/stevenson_screen/SPS30_StevensonScreen.FCStd
75.6 x 49.0 x 192.0 mm
GHOST_SPS30
GHOST_BMP280
GHOST_HTU21D
REF_PG7_hub_1
REF_PG7_hub_2
REF_PG7_setto
REF_raccordo_guaina

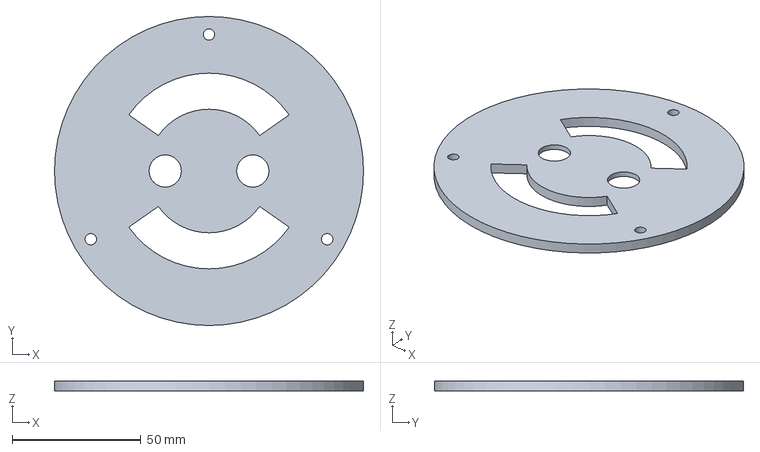
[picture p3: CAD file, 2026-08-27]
3d-printing/stevenson_screen/cable_hub.step
120.0 x 120.0 x 4.00 mm

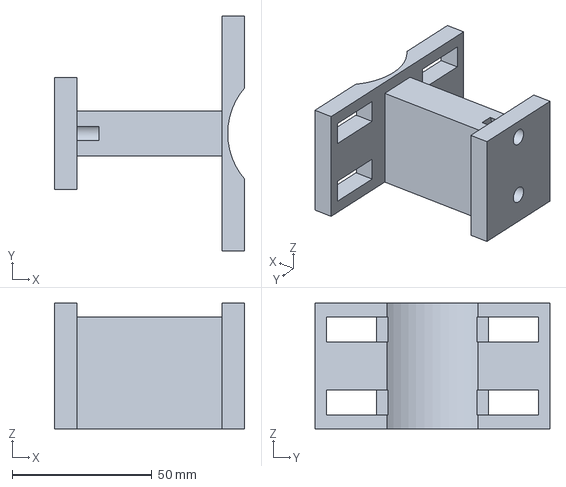
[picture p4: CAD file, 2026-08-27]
3d-printing/stevenson_screen/mast_bracket.step
68.0 x 84.0 x 45.0 mm

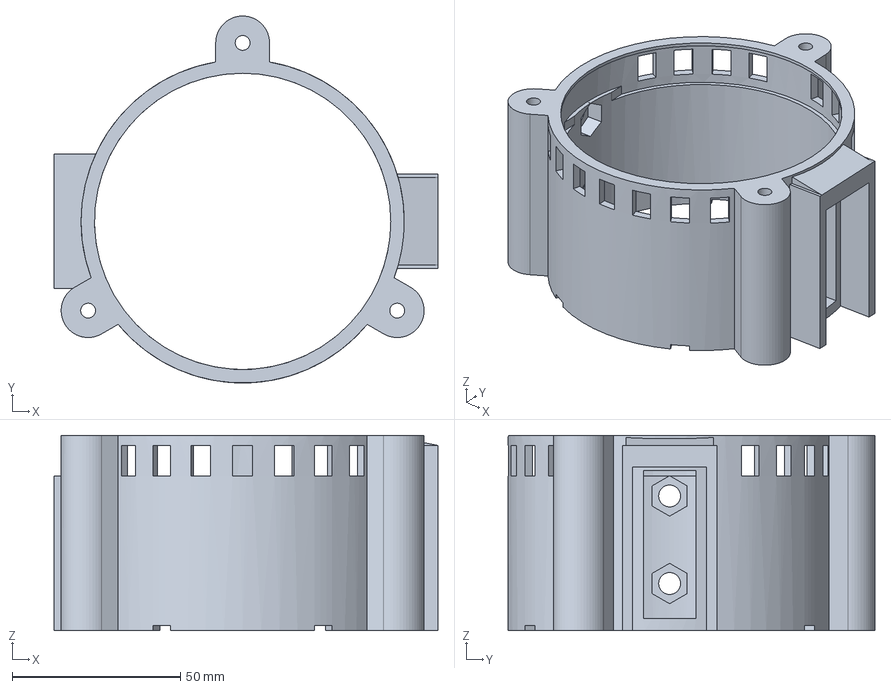
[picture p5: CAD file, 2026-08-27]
3d-printing/stevenson_screen/pm_body.step
114.0 x 109.0 x 58.0 mm

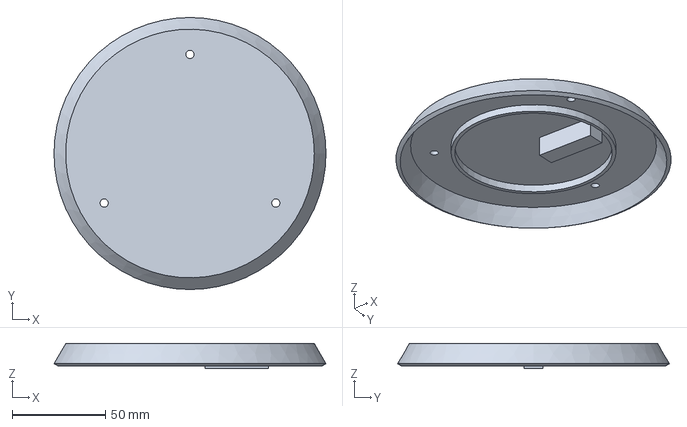
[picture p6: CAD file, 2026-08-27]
3d-printing/stevenson_screen/pm_lid.step
145.5 x 145.5 x 13.4 mm

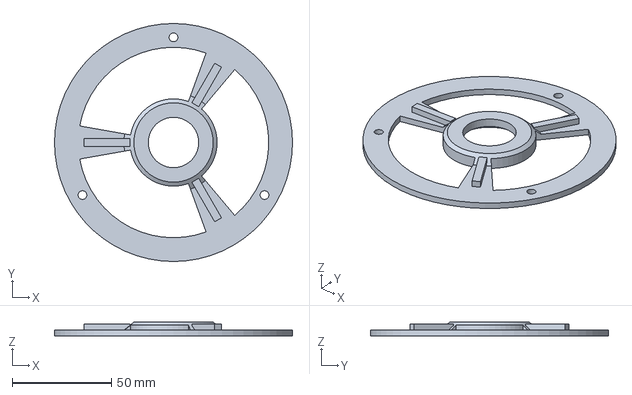
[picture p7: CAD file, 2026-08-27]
3d-printing/stevenson_screen/conduit_plate.step
120.0 x 120.0 x 7.00 mm

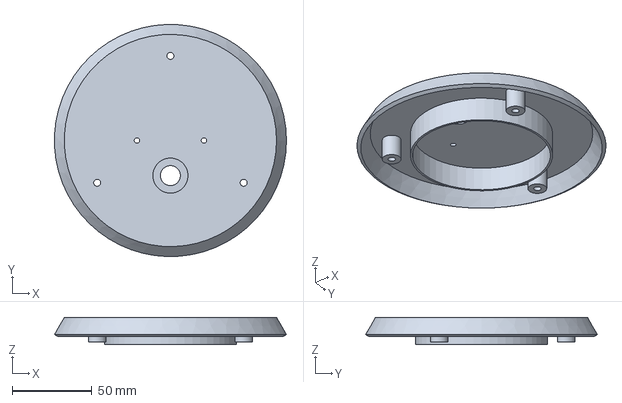
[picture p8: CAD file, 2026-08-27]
3d-printing/stevenson_screen/partition.step
145.4 x 145.5 x 17.2 mm

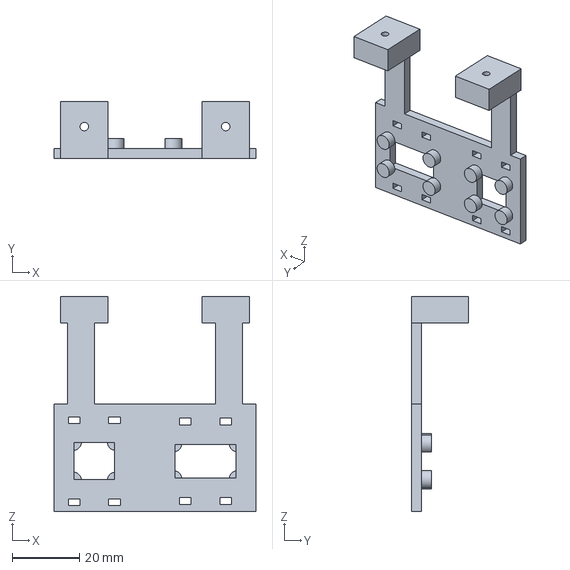
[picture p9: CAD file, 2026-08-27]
3d-printing/stevenson_screen/sensor_carrier.step
60.0 x 17.0 x 64.0 mm

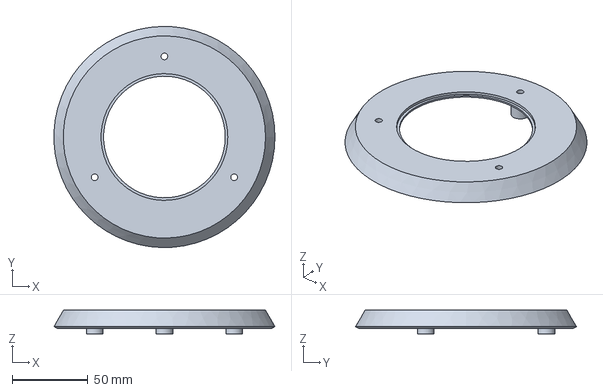
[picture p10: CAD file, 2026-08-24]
3d-printing/stevenson_screen/louver.step
145.4 x 145.5 x 15.6 mm

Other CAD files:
3d-printing/stevenson_screen/cable_hub.3mf
3d-printing/stevenson_screen/cable_hub.stl
3d-printing/stevenson_screen/conduit_plate.3mf
3d-printing/stevenson_screen/conduit_plate.stl
3d-printing/stevenson_screen/louver.3mf
3d-printing/stevenson_screen/louver.stl
3d-printing/stevenson_screen/louver_top.3mf
3d-printing/stevenson_screen/louver_top.stl
3d-printing/stevenson_screen/mast_bracket.3mf
3d-printing/stevenson_screen/mast_bracket.stl
3d-printing/stevenson_screen/partition.3mf
3d-printing/stevenson_screen/partition.stl
3d-printing/stevenson_screen/pm_body.3mf
3d-printing/stevenson_screen/pm_body.stl
3d-printing/stevenson_screen/pm_lid.3mf
3d-printing/stevenson_screen/pm_lid.stl
3d-printing/stevenson_screen/sensor_carrier.3mf
3d-printing/stevenson_screen/sensor_carrier.stl

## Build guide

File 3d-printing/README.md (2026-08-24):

# WeatherNet Hardware

3D-printable parts for probe enclosures and sensor mounts. Starting
with the probe enclosure; an anemometer, rain gauge, and wind vane are
expected to follow (see `PROJECT_SPEC.md` Section 12, which already
lists these as sensors a future probe should support).

## Layout

One subdirectory per physical part or assembly:

```
3d-printing/
├── stevenson_screen/
│   ├── README.md                     -- print settings, hardware (screws/heat-inserts), assembly notes
│   ├── SPS30_StevensonScreen.FCStd    -- working file (parametric CAD -- see "File formats" below)
│   ├── louver.step, louver.stl, louver.3mf                 (×5 at print time)
│   ├── plate_partition.step, plate_partition.stl, plate_partition.3mf
│   ├── pm_body.step, pm_body.stl, pm_body.3mf
│   ├── pm_lid.step, pm_lid.stl, pm_lid.3mf
│   ├── sensor_carrier.step, sensor_carrier.stl, sensor_carrier.3mf
│   └── mast_bracket.step, mast_bracket.stl, mast_bracket.3mf
└── anemometer/             (future)
```

Each part's own `README.md` should cover whatever a printer actually
needs to know: material, layer height/infill if it matters for fit or
strength, non-printed hardware required (screws, heat-set inserts,
bearings, ...), and any assembly notes.

## File formats

Two files per printable part, not one -- but which two depends on how
the part was actually made:

- **Modeled/edited in a parametric CAD tool** (FreeCAD, Fusion 360,
  ... -- see `stevenson_screen/`): keep the tool's native project file (e.g.
  `.FCStd`, `.f3d`) as the actual working file -- full parametric
  history, sketches, everything editable. Also export a **`.step`**
  (or `.stp`) alongside it, the closest thing to a universal,
  tool-independent CAD interchange format, so anyone (including
  future-you on a different machine, or someone without that specific
  tool) can still open and modify the geometry -- STEP round-trips
  geometry reliably, but not always every parametric feature/history
  the native format preserves, which is why both are kept, not just
  one. Then export a **`.stl`** for the slicer.
- **Modeled/edited directly as a mesh** (Blender, Meshmixer, or a
  slicer's own mesh tools like Bambu Studio's cut/scale/hole tools):
  there is no parametric history to preserve, so the tool's own
  **project file** (e.g. Bambu Studio's `.3mf`, PrusaSlicer's `.3mf`)
  *is* the most-editable form the design exists in -- keep that as the
  working file instead of a `.step` that wouldn't exist anyway. Still
  export a plain **`.stl`** alongside it for slicers/services that
  don't read the project format.

Either way, export STL as **binary**, not ASCII, when the tool offers
a choice -- same compatibility, a fraction of the file size. And
either way, never commit *only* the `.stl` for a part -- that's the
equivalent of shipping a compiled binary with no source, whether the
"source" is a `.step` or a mesh-editor project file.

## Licensing

**The rest of this repository is MIT-licensed; parts under `3d-printing/`
aren't necessarily.** Every part here so far *is* MIT (see each part's
own README for why, where it matters). But that won't always be true: 3D-printable
designs can easily start as an actual modification of someone else's
Creative-Commons-licensed model instead of a fresh build, in which case
that part's directory would carry the original's license forward, not
MIT.

Before reusing anything from a subdirectory here, check that
subdirectory's own `LICENSE`/`README.md` if one exists -- don't assume
the top-level `LICENSE` (MIT) covers it just because most parts happen
to be MIT today. And before *adding* a new part that's an actual
modification of someone else's design (as opposed to just inspired
by it): check what license they published it under, and if it requires
the derivative to carry the same license (most Creative Commons
"ShareAlike" variants do, as does the GPL family, if a design ever
comes from that world) or forbids commercial use, add a `LICENSE` file
to that part's own subdirectory documenting it, rather than assuming
MIT applies by default.

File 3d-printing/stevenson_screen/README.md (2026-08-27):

# Stevenson-screen-style radiation shield for SPS30 + BMP280 + HTU21D-F

Overall envelope **197 × 145 × 154 mm** (bracket included). Shield Ø 145.5 mm, height 154 mm.
Material **ASA**. Estimated mass ~239 g at 35% infill.

## Why it's built this way

Two stacked chambers separated by a solid partition:

- **PM chamber (top)** — the SPS30 sits vertically with its ports facing radially
  outward and **rotated so the two inlets sit above the outlet**: this is the
  "side mounting" called for by Sensirion's own mechanical guidelines, which
  prevents already-measured particles from falling back into the inlets under gravity.
  The sensor is up top on purpose: it dissipates ~0.3 W and Sensirion recommends
  keeping it away from or below heat sources — here the sensor itself is the heat
  source, so convection carries its heat up and out, away from the climate sensors.
- **Solid partition** — breaks the chimney effect between the two chambers.
- **T/RH chamber (bottom)** — 5 louver plates with a 60° skirt, open bottom,
  BMP280 and HTU21D-F on a panel suspended in the middle, ventilated on both faces.

The sensor's port face sits **flush with the outer wall**: its nose enters the
opening, which is deliberately 2.8 mm narrower than the sensor (15.6 vs 12.8 mm).
A **foam collar** wrapped around the nose fills the 1.4 mm gap per side. This stops
exhaust air from looping around the sensor inside the chamber and re-entering the
inlets; without it the leak path (64 mm2) would be wider than the outlet itself
(23 mm2). Openings stay large and in direct contact with ambient air, as Sensirion
requires.
Rain protection: a 45° drip edge, two vertical cheeks, and above all the
Ø 130 mm roof, which overhangs the wall by 22 mm with a skirt that comes down
to 1 mm above the opening's top edge.

## Printed parts list

| STL file | Qty | Envelope | Print orientation |
|---|---|---|---|
| `louver` | 7 | 146 × 146 × 16 | **upside down**, flat face on the bed |
| `partition` | 1 | 146 × 146 × 17 | **upside down**, flat face on the bed |
| `pm_body` | 1 | 114 × 109 × 58 | upright, base on the bed |
| `pm_lid` | 1 | 146 × 146 × 14 | **upside down**, roof on the bed |
| `sensor_carrier` | 1 | 60 × 17 × 64 | on its side, panel on the bed |
| `cable_hub` | 1 | Ø120 × 4 | flat on the bed |
| `conduit_plate` | 1 | Ø120 × 7 | flat on the bed |

In these orientations, unsupported overhangs are ≤ 4% of the area and are only
short bridges (opening's ceiling, louver slots, slots): **no supports needed**.
Requires a bed of at least 150 × 150 mm.

## Hardware

All dimensions taken from the current model, not from memory.

| # | Item | Qty | Where it goes |
|---|---|---|---|
| 1 | M4 stainless threaded rod, **180 mm** | 3 | Through the 3 boss columns, bottom to top |
| 1 | M4 nyloc nut + washer | 6 | 3 under the lowest bosses, 3 on top of the roof |
| 2 | **M3 x 12** self-tapping screw | 2 | From above, through the partition at x = +/-21, into the carrier tabs |
| 3 | 2.5 mm cable tie | 4 | Two per breakout board, looped vertically through the 3.5 x 2.0 mm slots |
| 4 | Foam collar, **3 mm** thick, ~5 mm wide, ~110 mm long | 1 | Wrapped around the SPS30 nose, all four sides |
| 5 | **M6 x 25** hex-head bolt + nyloc nut + washer | 2 | Head drops into the hex pockets from *inside*; nut goes on outside |
| 6 | M8 U-bolt (or metal hose clamp) | 2 | Through the four 22 x 9 mm slots in the saddle plate |
| 7 | Insect mesh basket, **O83 x 77 mm** | 1 | Central aperture of the louver stack |
| 8 | Insect mesh strip, **13 x 285 mm** | 1 | Annular seat inside the PM module, behind the vent slots |
| 9 | Rubber cable gland, **O13 mm** (split type) | 1 | Partition hole at (0, -18) |
| 10 | Foam, 1 mm | 2 | One strip behind the SPS30, one pad under the lid rib |
| 11 | **PG7** cable gland | 3 | In `cable_hub`, Ø12.5 holes 34 mm apart. Body underneath, locknut on top; fit before stacking plate 2 |
| 12 | **M25** conduit-to-box fitting | 1 | Ø25.4 hole in `conduit_plate`, ring nut on top |
| 13 | **Ø25** corrugated conduit | 1 | From the fitting down the mast to the Raspberry Pi |

Notes on sizing:

- **Rod length.** Clamped stack is 154.2 mm (lowest boss to roof top). Adding a washer,
  a nyloc nut and 2 mm of thread at each end gives 180 mm. Cut three from a 1 m rod.
- **Washers.** The bosses are only O11, so the bottom washers must be standard DIN 125
  (O9). Wide washers only fit on top, where they bear on the flat roof.
- **M3 length.** 2.6 mm of partition + 8 mm of engagement in the carrier tab = 10.6 mm.
  M3 x 16 would bottom out; use **M3 x 12**.
- **M6 length.** 7 mm of boss in tension + 8 mm bracket + washer + nyloc = 21.6 mm under
  the head. The pocket is 10.4 mm across flats against a 10.0 mm head, so the bolt can
  turn only +/-4.5 deg before it locks: tighten the nut only.
- **Cable gland.** Use a split/openable one. The ZHR-5 connector will not pass through a
  closed grommet, and you do not want to solder it on afterwards.

**No heat-set inserts are used anymore** — the M6 captive bolts replaced them.

## Insect mesh

Outdoors a louvered shield quickly becomes a wasp nest, so two seats are provided:

- **T/RH chamber**: every louver plate has an O83.4 x 1.6 mm rebate on its top face.
  Roll a O83 mesh basket (cylinder plus a bottom disc), drop it in from above before
  fitting the partition. It springs into the rebates and rests on the step of the
  lowest plate, so it cannot fall through. No glue.
- **PM module**: an annular seat is recessed into the inner wall across the vent band.
  A 13 mm tall strip holds itself by spring force.

Stainless or fibreglass mesh, 0.8-1 mm aperture. Do not go finer or you choke the airflow.

**Do not put mesh over the SPS30 ports** — Sensirion requires inlets and outlet to stay
unobstructed; a screen in front clogs and crops the large particles, skewing PM10 while
the sensor keeps returning plausible numbers. Leave the four 1.6 mm drain notches open
too, or they stop draining.

## Cable routing

Two Cat5e cables leave the shield downwards: one for the SPS30 on **UART**, one
shared by BMP280 and HTU21D-F on I2C. Sensirion recommends UART for any connection
cable longer than 20 cm, and warns to keep I2C runs under 10 cm, so the PM sensor
gets the robust link and only the two low-rate sensors share a bus.
Set `N_CABLE` in the macro if you want three instead.

- **SPS30** is the only cable that crosses the partition: down through a PG7 gland in the Ø12.5 hole at (0, -22), into the T/RH chamber.
- **BMP280** and **HTU21D-F** are already below the partition and drop straight down.
- All two leave through `cable_hub`, a Ø120 disc that sits on the top face of the lowest
  louver plate and is clamped by the bosses of the plate above, on the same three tie
  rods. It is not just resting. `N_CABLE` Ø6.6 holes (snug on 5.0-5.5 mm Cat5e), a pair of slots
  beside each hole for a cable-tie strain relief, and three openings that keep 44% of
  the bottom aperture free for airflow.
- The mesh basket sits on top of the hub, so the mesh itself is never pierced: the hub
  is the single crossing point and the cables seal it themselves.

### Conduit

`conduit_plate` sits under the lowest louver plate and is clamped by the same three tie
rods, so the conduit is anchored to the structure and not hanging off the cables. It
carries a Ø25.4 hole for an **M25 conduit-to-box fitting**, on a 4 mm conical weir, so water
would have to pond more than 4 mm deep across the whole plate to reach it, plus three openings and three ribs.

**Size:** with two cables, Ø20 works: rigid Ø20 (16.9 mm bore) is fine up to Ø6.5 mm
cable, corrugated Ø20 (14.1 mm bore) only up to Ø5.5. Measure your cable first.

Drill a small **weep hole at the lowest point of the conduit run**: whatever gets in at either end leaves there. This, not the choice of exit point, is what keeps the Pi dry.

**The conduit must run downwards the whole way.** Do not take it up over the shield: the
shield would become the high point and every drop of rain or condensate inside the
conduit would drain into the Pi. End the conduit *below* the Raspberry Pi enclosure,
open and facing down so it drains, and bring the cables up into a gland on the bottom
of the box.

Leave slack outside for a **drip loop** — the lowest point of each cable must be clear
of the shield, so water drips there instead of tracking up into the housing. Tie the
cables to the mast below the loop, then run them to the Raspberry Pi enclosure.

The T/RH chamber is ventilated by design, so these holes do not need to be watertight;
they only need to keep insects out.

## Assembly

1. Thread the 3 rods; stack from the bottom: nut + washer, 5 `louver` plates,
   `partition`. The built-in bosses set the 15.6 mm pitch on their own.
2. Drop `cable_hub` into the rebate of the lowest plate, then the mesh basket on top
   of it, before the partition goes on.
3. Mount BMP280 and HTU21D-F on the `sensor_carrier`: they sit on the four 3 mm
   standoffs (air on both faces), one cable tie per board holds them. STEMMA QT
   connectors stay clear on the short sides.
4. Screw the `sensor_carrier` under the partition, 2x M3 x 12 from above.
5. Wrap the foam collar around the SPS30 nose, flush with the port face but **not over
   the slots**. Lower the sensor into the cradle, **inlets on top**, and push the nose
   into the opening until the face is flush with the outer wall.
   Add the 1 mm foam behind it, against the rear stops.
6. Feed the cable through the split gland in the partition *before* plugging it in.
7. Press the mesh strip into the annular seat of the PM module.
8. Drop the two M6 bolts into the hex pockets from inside, while the lid is still off.
9. Close with `pm_lid` (1 mm foam pad under the internal rib). Nyloc nuts on top of the
   roof, snug only.
10. Pull the two Cat5e cables through `cable_hub`, one cable tie each as strain
    relief, and form the drip loop before running them to the Raspberry Pi.

Point the port opening **away from the mast and from prevailing rain-bearing winds**.

## Printing (ASA)

Nozzle 250-260 °C, bed 100-110 °C, **enclosed chamber** and no drafts.
0.4 mm nozzle, 0.2 mm layers, 4 perimeters, 5 top/bottom layers, 30-40% infill
(gyroid). Fan 0-20%. ASA is the right choice here: it resists UV, which PLA
and PETG don't outdoors. If a part lifts off the bed, use a 5 mm brim on the plates.

## Main parameters (top of the `.FCMacro` file)

`D_PLATE` plate diameter · `GAP` clearance between plates · `N_LOUVER` number of plates
`SKIRT_L` / `SKIRT_A` skirt geometry · `H_PM` PM chamber height
`BMP_X/Z`, `HTU_X/Z` breakout board envelope · `MAST_Z` bracket mounting spacing

Edit and re-run: everything regenerates, assembly and exports included.

## Already verified

- 6 topologically valid solids (`BRepCheck_Analyzer`)
- 0 interferences between assembly parts (pairwise boolean checks)
- all three sensors have collision-free clearance
- unsupported overhangs ≤ 4% for every part in the orientation shown

## Known limitations

- The roof is **flat** (so it can print upside down without supports). It sheds
  water fine thanks to the skirt, but if you want a dome, print it upright with a brim.
- The SPS30's ZHR-5 connector vertical clearance isn't specified in the
  datasheet: the rear standoffs were kept low (z 0-17 mm) to leave it clear,
  but verify on the first dry-fit assembly.
- The Adafruit breakout boards are held by standoffs + a cable tie rather than
  screws through the corner holes, because Adafruit doesn't publish the hole
  spacing: this way the mount works regardless of board tolerance.

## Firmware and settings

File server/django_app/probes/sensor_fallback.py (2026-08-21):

"""Canonical, public-facing sensor field names, each backed by one or
more concrete `sensor_type` strings in priority order.

BME680 (this project's original sensor) is preferred when a probe has
it; the newer chip-specific sensors (see weathernet_probe/sensors/
bmp280.py, htu21d.py -- their sensor_type values are chip-prefixed
precisely so they can coexist with BME680's without colliding, per the
README's wiring section) act as a fallback so callers never need to
know or care which hardware a given probe actually has.

Shared by the public API views (views.py) and the Telegram daily
digest (subscriptions/management/commands/send_daily_digest.py) --
both need the exact same fallback policy, and duplicating these tuples
in two places would risk them drifting out of sync whenever a new
sensor is added.

There's no equivalent of BME680's gas_resistance_ohm on the other
sensors, so that one has no fallback list -- a probe without BME680
simply reports no gas reading / no AQI, same as before any fallback
existed.
"""

TEMPERATURE_SENSOR_TYPES = ("temperature_c", "bmp280_temperature_c", "htu21d_temperature_c")
HUMIDITY_SENSOR_TYPES = ("humidity_pct", "htu21d_humidity_pct")
PRESSURE_SENSOR_TYPES = ("pressure_hpa", "bmp280_pressure_hpa")
GAS_SENSOR_TYPES = ("gas_resistance_ohm",)

# PM2.5/PM10 have no fallback chain (SPS30 is the only sensor that
# reports them) -- named here anyway so the AQI computation
# (probes/aqi.py's compute_overall_air_quality_index) and anything
# that needs to query for the latest reading share the exact same
# sensor_type strings as sensors/sps30.py, rather than repeating the
# literal string in three places.
PM25_SENSOR_TYPE = "sps30_pm2_5_ug_m3"
PM10_SENSOR_TYPE = "sps30_pm10_ug_m3"
PM_SENSOR_TYPES = (PM25_SENSOR_TYPE, PM10_SENSOR_TYPE)

ALL_SENSOR_TYPES = TEMPERATURE_SENSOR_TYPES + HUMIDITY_SENSOR_TYPES + PRESSURE_SENSOR_TYPES + GAS_SENSOR_TYPES

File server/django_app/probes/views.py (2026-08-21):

import hashlib
import hmac
import logging
import uuid
from datetime import timedelta

from django.conf import settings
from django.db import transaction
from django.db.models import Max
from django.utils import timezone
from rest_framework.response import Response
from rest_framework.views import APIView

from telemetry.models import SensorReading

from . import ca, ssh
from .aqi import compute_overall_air_quality_index
from .models import EnrollmentToken, Probe
from .sensor_fallback import ALL_SENSOR_TYPES as PUBLIC_SUMMARY_SENSOR_TYPES
from .sensor_fallback import HUMIDITY_SENSOR_TYPES as PUBLIC_HUMIDITY_SENSOR_TYPES
from .sensor_fallback import PM10_SENSOR_TYPE, PM25_SENSOR_TYPE, PM_SENSOR_TYPES
from .sensor_fallback import PRESSURE_SENSOR_TYPES as PUBLIC_PRESSURE_SENSOR_TYPES
from .sensor_fallback import TEMPERATURE_SENSOR_TYPES as PUBLIC_TEMPERATURE_SENSOR_TYPES
from .serializers import EnrollRequestSerializer
from .wireguard import (
    SubnetExhaustedError,
    allocate_tunnel_ip,
    read_server_public_key,
    server_tunnel_ip,
)

logger = logging.getLogger(__name__)

DEFAULT_REPORT_INTERVAL_SECONDS = 300
# See sensor_fallback.py for what these mean and why BME680 is
# preferred over the newer chip-specific sensors when both exist.
PUBLIC_SUMMARY_GAS_BASELINE_WINDOW = timedelta(days=7)
PUBLIC_HISTORY_DEFAULT_HOURS = 24
PUBLIC_HISTORY_MAX_HOURS = 168  # 7 days -- a public, keyed-but-not-per-request-limited
# endpoint shouldn't let a caller ask for an unbounded history query.


def _check_public_api_key(request):
    """Shared gate for every /api/v1/public/* view. Returns an error
    Response if the request should be rejected, None if it may proceed.

    An unset PUBLIC_SUMMARY_API_KEY means the whole public API surface
    is disabled, not open -- compare_digest("", "") is True, so the
    emptiness is checked separately rather than relying on the digest
    compare alone.
    """
    configured_key = settings.PUBLIC_SUMMARY_API_KEY
    provided_key = request.headers.get("X-Api-Key", "")
    if not configured_key or not hmac.compare_digest(provided_key, configured_key):
        return Response({"detail": "invalid or missing API key"}, status=401)
    return None


def _air_quality_fields(pm25, pm10, gas_resistance, gas_baseline, humidity):
    """Builds the `air_quality_index`/`air_quality_index_scale` pair
    for the public API response. The scale field exists because the
    two possible sources (see aqi.py's compute_overall_air_quality_index)
    are on genuinely different scales -- "epa" is 0-500+ with EPA's six
    named categories, "heuristic" is the older 0-100 BME680-only
    fallback -- a consumer of this API needs to know which one it's
    looking at to render it correctly (e.g. public-page/'s gauge
    color/label logic), not assume either.
    """
    value, is_epa = compute_overall_air_quality_index(pm25, pm10, gas_resistance, gas_baseline, humidity)
    return {
        "air_quality_index": value,
        "air_quality_index_scale": "epa" if is_epa else "heuristic",
    }


def _most_recent_available(readings: dict, sensor_types: tuple):
    """Among sensor_types, the value belonging to whichever one's own
    latest reading is actually the most recent -- e.g. BMP280's
    chip-prefixed temperature_c if a probe switched to it and BME680
    hasn't reported since, even though BME680's generic sensor_type is
    earlier in priority order. `readings` maps sensor_type -> (value,
    time), per probe (see PublicSummaryView.get()).

    This is *not* just "first non-None in priority order": that would
    keep returning a stale value from a sensor_type the probe used to
    report under (mock sensors and BME680 both use the generic
    "temperature_c") forever after the probe's hardware changed to a
    chip-prefixed one -- the old row never stops being "the latest
    temperature_c row that ever existed" without a recency comparison,
    which is exactly the bug this replaced. Ties (identical timestamps
    -- realistically only in tests) fall back to priority order, since
    that's the iteration order sensor_types is walked in.

    None if none of sensor_types have ever reported for this probe.
    """
    candidates = [readings[sensor_type] for sensor_type in sensor_types if sensor_type in readings]
    if not candidates:
        return None
    value, _time = max(candidates, key=lambda pair: pair[1])
    return value


def _latest_value(readings: dict, sensor_type: str):
    """Single-source fields (gas_resistance_ohm, the PM sensor types)
    have no fallback list to pick among -- just unwrap the (value,
    time) pair _most_recent_available's callers otherwise deal with.
    """
    pair = readings.get(sensor_type)
    return pair[0] if pair else None


def _first_non_empty_series(probe_series: dict, sensor_types: tuple):
    """Similar coalescing idea to _most_recent_available, but for a
    whole time series: the first non-empty list among sensor_types, in
    priority order. Simple existence-in-priority-order (not a recency
    comparison like _most_recent_available needs) is correct here
    specifically because the caller already bounds the query to a
    fixed recent window (PublicHistoryView.get()'s `hours` param) --
    unlike PublicSummaryView's "latest ever" query, a stale sensor_type
    from a probe's old hardware simply won't appear in `probe_series`
    at all once it falls outside that window, so there's no staleness
    case to get wrong here. [] if none of them have any points in the
    requested window.
    """
    for sensor_type in sensor_types:
        series = probe_series.get(sensor_type)
        if series:
            return series
    return []


def _public_probes_queryset():
    """Probes eligible to appear anywhere in the public API: active,
    and with coordinates set (an operator hasn't necessarily filled
    those in for every probe -- see Probe.location_latitude/longitude).
    """
    return Probe.objects.filter(
        is_active=True,
        location_latitude__isnull=False,
        location_longitude__isnull=False,
    )
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

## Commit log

2024-10-01 Few changes to the script hoping to avoid overloading the sensor Service file to automatically start the service at boot
2026-08-17 New - and better - enrollment procedure for probes
2026-08-17 Small fix for Raspberry Pi 3
2026-08-17 Fix to set-up probes
    [views.py]
2026-08-17 Small wireguard fix
2026-08-17 More details about the probes
2026-08-17 Small fix to restart wireguard on the probe
2026-08-17 Fix probe reading
2026-08-21 3d models for enclosures and covers
    [case.3mf, case.FCStd, case.step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]
2026-08-21 Added new sensors: BMP280, HTU21D-F, SPS30
2026-08-21 Fallback public sensors Undervoltage tracking Some other fixes to public interface
    [models.py, sensor_fallback.py, serializers.py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]
2026-08-21 Switching to UART for SPS30
2026-08-21 Temporary files going on FreeCAD schemas
    [case.3mf, case.FCStd, case.step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]
2026-08-24 Specify better how to activate sensors
2026-08-24 Fix for public page - delete cache for inactive probes
2026-08-24 New design
    [SPS30_StevensonScreen.FCStd, case.3mf, case.FCStd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]
2026-08-24 Removed mast_bracket since it is useless. Everyone will use their own bracket.
    [SPS30_StevensonScreen.FCStd, mast_bracket.3mf, mast_bracket.step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]
2026-08-25 New drawings for extra two parts
    [SPS30_StevensonScreen.FCStd, cable_hub.3mf, cable_hub.step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]
2026-08-26 Small fixes to a few parts
    [SPS30_StevensonScreen.FCStd, cable_hub.3mf, cable_hub.step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]
2026-08-27 Some fixes to the screen for better and easier assembling.
    [SPS30_StevensonScreen.FCStd, cable_hub.3mf, cable_hub.step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]
2026-08-31 Final design
    [SPS30_StevensonScreen.FCStd, louver_top.3mf, louver_top.step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]

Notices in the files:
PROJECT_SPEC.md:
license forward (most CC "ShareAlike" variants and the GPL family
